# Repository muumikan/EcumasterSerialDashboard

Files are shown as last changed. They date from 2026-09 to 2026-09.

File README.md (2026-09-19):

# Ecumaster EMU Classic serial dashboard

A digital dashboard for a Toyota Carina with a 1G-GTE running an Ecumaster
EMU Classic. An ESP32-S3 reads the ECU's serial data stream and renders it on
a 3.5" touch panel.

**The link is read-only.** Nothing in the firmware writes to the ECU port,
and the ECU's extension port is a one-way stream in the first place.

## Hardware

| Part | Detail |
|---|---|
| Display / MCU | Elecrow CrowPanel Advance 3.5" HMI, ESP32-S3-WROOM-1-N16R8 |
| Panel | ILI9488, 480 × 320 IPS, GT911 capacitive touch |
| Memory | 16 MB flash, 8 MB octal PSRAM |
| Level shifter | MAX3232 (RS-232 ↔ 3.3 V TTL) |
| Clock | BM8563 RTC at 0x51, CR1220 cell diode-OR'd through a BAT54C |
| Storage | microSD on its own SPI bus, FAT16/FAT32 |
| ECU | Ecumaster EMU Classic, firmware 1.211 |
| Link | EDL-1 logger stream, 115200 baud, 8N1, one direction only |
| ECU port | EMU Classic extension port (replaces the BT Module) |

The dashboard replaces the Ecumaster BT Module on the EMU Classic's extension
port. That port speaks RS-232 voltage levels, which would destroy an ESP32
GPIO, so a MAX3232 sits between them — powered from the ECU at 3.3 V, never
5 V. See [wiring/signal-list.md](wiring/signal-list.md); the supply rule there
is the one that decides whether the board survives.

## What it shows

Eight pages, switched by swiping horizontally. Only channels that have a sensor
actually fitted to the car appear anywhere; VSS and EGT are streamed by the
ECU but not wired, so they are not displayed.

The pictures below are drawings of each page at the panel's own 480 × 320,
produced by [docs/mockup/render.py](docs/mockup/render.py) from the same
numbers the firmware uses. They are not screenshots — nothing here has been
photographed off the panel yet — so treat them as the layout, not as proof it
renders this way.

| | |
|---|---|
| **1 · Drive** — RPM, boost with peak hold, CLT, oil pressure, lambda, battery | **2 · Tune** — AFR against target, knock, ignition, injector PW and duty, MAP, TPS, RPM |
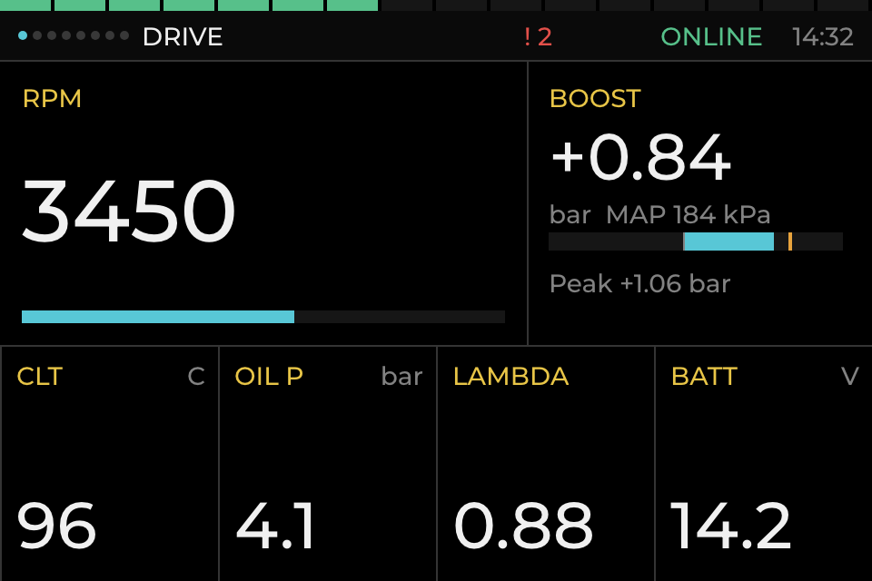
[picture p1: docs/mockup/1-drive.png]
Drive
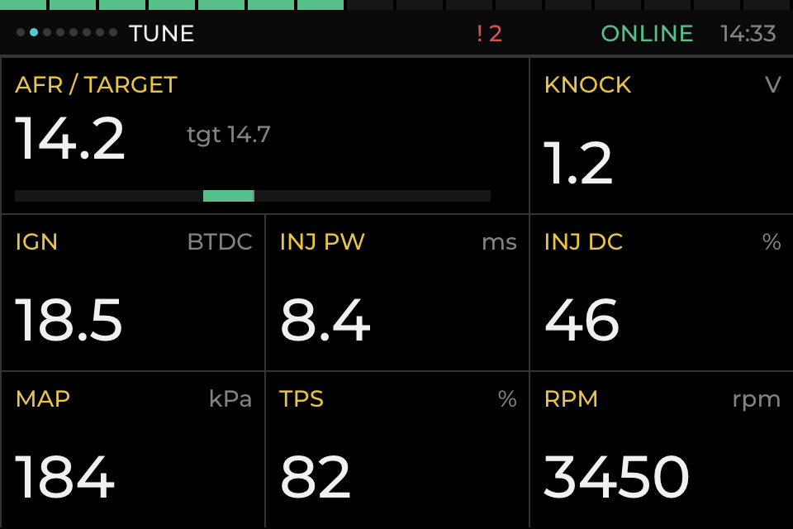
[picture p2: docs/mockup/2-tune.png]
Tune
|  |  |
| **3 · Temps** — CLT, IAT, ECU temp, oil pressure, fuel pressure, ΔFPR | **4 · Idle** — RPM against the idle target, valve duty, the PID's share, timing trim |
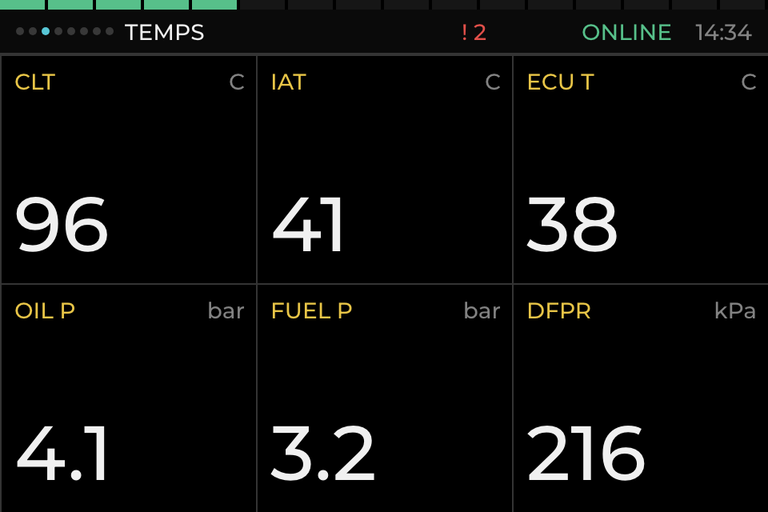
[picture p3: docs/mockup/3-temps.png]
Temps
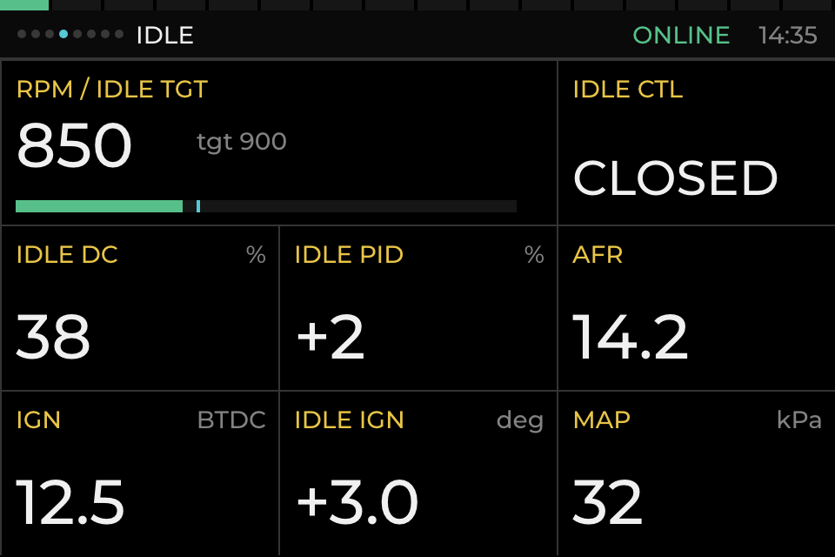
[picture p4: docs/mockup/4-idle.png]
Idle
|  |  |
| **5 · Boost** — MAP against the boost target, solenoid duty, PID and error correction | **6 · Alarms** — everything that tripped this run, newest first, with the time |
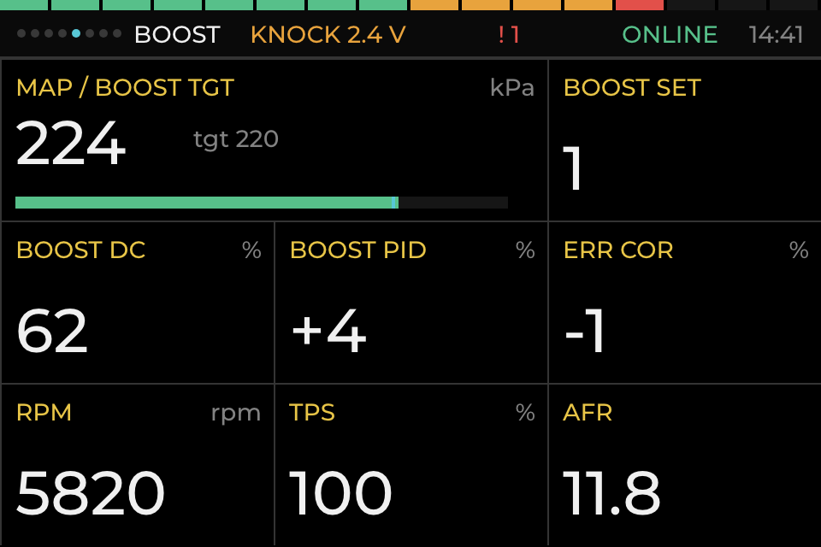
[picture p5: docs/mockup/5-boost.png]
Boost
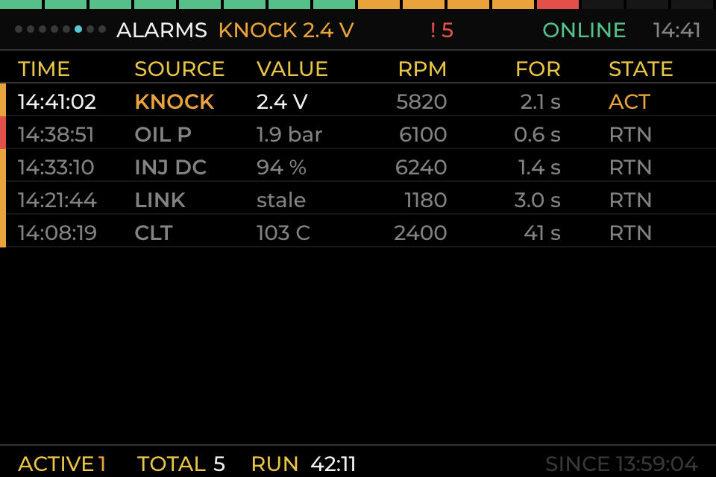
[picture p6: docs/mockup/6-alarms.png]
Alarms
|  |  |
| **7 · Diag** — link state, frame age, counters, what latched, CEL word, run peaks | **8 · Setup** — alarm limits and behaviour, shift points, brightness, logging |
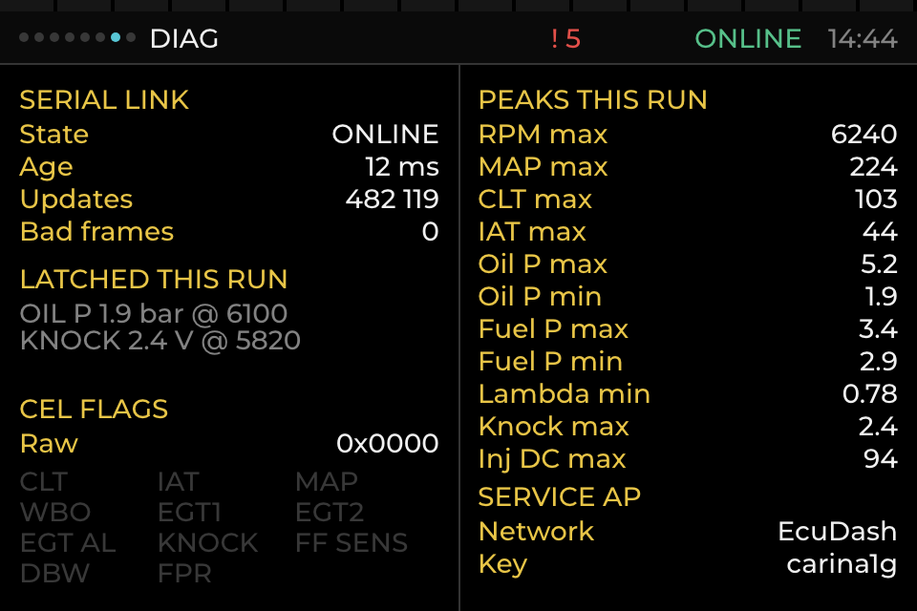
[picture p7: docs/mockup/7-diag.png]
Diag
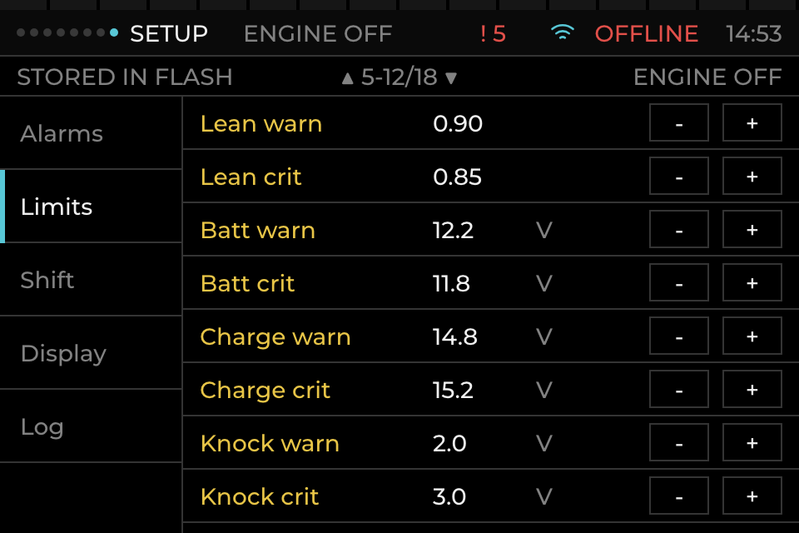
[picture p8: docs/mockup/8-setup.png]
Setup
|  |  |

Idle and Boost are pit work rather than driving pages, which is why they sit
after Temps rather than next to Tune. Both need the EDL-1 stream's control
channels; on a car whose ECU does not send them, they say so instead of
drawing zeros.

A measurement's name is yellow and its value white, everywhere on the
dashboard. Grey on black was the lowest contrast on the panel and it was on
the one element that says what you are looking at; yellow on black is also
what an Ecumaster dash looks like, so the panel matches the software beside
it.

Parked, with the engine stopped and the service access point up, the same
Drive page reads like this — the oil pressure cell showing what a critical
alarm does to a cell, and the status bar carrying the access point, a latched
count and the link all at once:

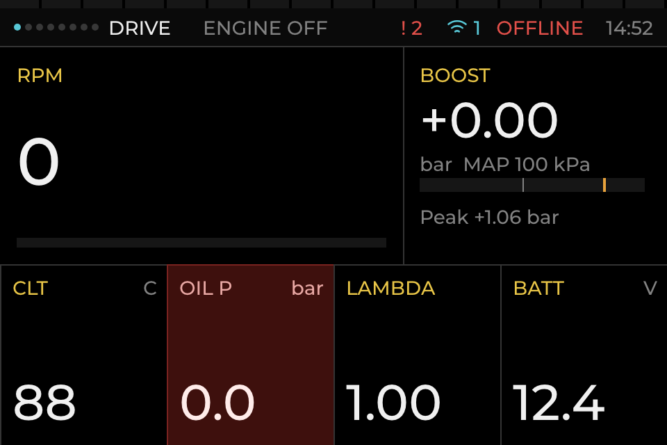
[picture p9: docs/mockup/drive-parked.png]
Drive, parked, with the access point up


Above every page sit two always-on layers: a 6 px shift-light strip, lit from
1 000 rpm and red from 6 000, and a status bar carrying the link state, the
worst active alarm and the time of day regardless of which page is up. The car
has no clock in its own instrument cluster, so this is the only one.

The page changes only when you swipe it. There is no idle timeout returning to
Drive: on the car it moved the screen out from under you while you were still
reading it.

An out-of-range value lights its own cell — amber for a warning, red for
critical — and names itself in the status bar. Nothing but a swipe ever changes
the page. Every trip is recorded with its time, the value, the RPM it happened
at and how long it lasted, so a half-second dip is still there when you stop.

The Alarms page lists those records newest first. Limit crossings, the ECU's
check-engine bits and the health of the serial link all land in the same list,
because a loose connector and a hot engine are both things you want to see in
the order they happened. Nothing is acknowledged and nothing is cleared by
hand: it is a log to read, not a queue to work through.

Alarms arm only after the engine has been running for a few seconds. Cranking
crosses 500 rpm while oil pressure is still building and the battery is still
down from the starter, and without the delay every start would fire two
critical alarms. Thresholds carry a deadband so a value sitting on its limit
does not flicker.

Limits, the arming delay, the deadband, the shift points and the backlight are
all editable on the Setup page and stored in flash — no laptop, no reflash. The
page stays usable with the engine running, because setting a limit without
watching the value it guards is guesswork.

At power-up the dash opens on Drive and sweeps the shift lights, so every
segment is confirmed working before the car moves.

## The serial link

The dashboard reads the EMU's **EDL-1** logger stream: 260-byte frames at
115200 baud carrying all 195 channels from one instant, rather than the older
protocol's 34 channels arriving one 5-byte frame at a time. The ECU has to be
configured to send it.

The classic protocol was supported too, chosen by a build flag, until it was
removed — it could not produce a `.emulog` at all, and was compiled on every
change without ever being run. See the
[decision log](docs/decision-log.md). The adapter seam it justified is still
there, so adding a protocol back costs nothing above that line.

The channels are listed in [docs/edl-channels.md](docs/edl-channels.md); most
are not on screen yet.

## Service page

With the engine stopped, the dashboard raises a WiFi access point and serves a
maintenance page on it: download or delete the logs, edit the same settings the
panel holds, set the clock from the browser, and read the diagnostics that
otherwise need a USB cable behind the dash.

Join `EcuDash` and open `http://192.168.4.1/`. It is off until switched on
under `Log` on the setup page. Full details, including why the engine has to be
stopped, are in [docs/service-page.md](docs/service-page.md).

## Building

The project uses [PlatformIO](https://platformio.org/).

```bash
pio run                     # build
pio run -t upload           # build and flash over USB-C
pio device monitor          # 115200 baud USB CDC console; press any key for the state
```

There is one environment, `crowpanel_advance_35`, so no `-e` is needed. If
`pio` is not on your `PATH`, it lives at `~/.platformio/penv/bin/pio`.

Dependencies (LovyanGFX and LVGL 8.3) are pulled automatically. The EDL-1 field
extraction is vendored in `lib/EDLSerial/` — it is
[ThiloZ/EDLSerial](https://github.com/ThiloZ/EDLSerial) (MIT), with the framing
done in this project instead; see
[docs/architecture.md](docs/architecture.md) for why.

## Layout

```
include/            headers, one per module
src/protocol/       EdlSerialAdapter — the only place that knows the wire format
src/data_model/     EngineDataModel — the single source of truth for the UI
src/ecu/            EcuDataProvider — owns UART1
src/alarms/         AlarmEngine — thresholds in one rule table, and the event log
src/screens/        LVGL pages, tiles, chrome and navigation
src/diagnostics/    diagnostics page and the serial text report
src/logging/        EmuLog — .emulog files to the SD card
src/hal/            display, touch and RTC bring-up
src/web/            service access point, HTTP server and the page it serves
docs/               architecture, protocol, decisions, vendor change logs
docs/mockup/        drawings of the eight pages, and the script that makes them
hardware/ wiring/   pin assignment and the ECU-to-dash signal chain
```

See [docs/architecture.md](docs/architecture.md) for how the layers fit
together and [docs/decision-log.md](docs/decision-log.md) for why they are
shaped that way.

## Status

**Runs on the car.** Tested connected to the ECU on 8 and 9 September 2026. On
EDL-1 the link runs clean with no dropped frames, values read correctly and the
alarm list behaves. See [docs/test-results.md](docs/test-results.md).

Working: the EDL-1 link, data model, alarm engine, eight pages, swipe
navigation, settings in flash, the real-time clock, SD logging, and the service
access point with its page — access point, page, log download and clock sync
confirmed on the car on 16 September 2026.

The 19 September session found three defects, all fixed: the SETUP page's
Limits category rebooted the board by exhausting LVGL's object pool, and every
write the service page accepts was refused because a dead ECU leaves its last
rpm frozen in the snapshot, which then reads as a running engine. Logs are
written into a folder per day from that session on.

Not yet exercised on the car: the multi-file `.tar` download, deleting logs,
starting the engine mid-download, and the idle timeout. They are listed with
what to look for in [docs/test-results.md](docs/test-results.md).

One thing to know about the parts that work. The SD card has mounted intermittently
on the bench for reasons nobody has established; `EmuLog` retries and says
which attempt worked, so the console tells you if it happens again.

Open items are listed in [docs/decision-log.md](docs/decision-log.md).

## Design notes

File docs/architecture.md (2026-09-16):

# Architecture

The rule the code is written against: **the UI never learns the wire format,
and the protocol layer never learns about timing or pixels.** Each layer below
only knows the one under it.

```
   ServicePage ◀── ServiceAp     WiFi access point, engine stopped only
        │                        logs, settings, clock, diagnostics
        │
        ▼
        LVGL screens              DashUi, MainScreen, TuneScreen, TempsScreen,
              │                   IdleScreen, BoostScreen, AlarmsScreen,
              │                   DiagnosticScreen, SetupScreen, Tile
              │
              │   DashSettings ◀──▶ SettingsStore (NVS)
              │        │            numbers and flags only
              │        │            SetupItem table shared by both editors
              ▼        ▼
        AlarmEngine ──────────┐   one rule table, limits from settings
              │               │   arming delay, hysteresis, latching
              ▼               ▼
        EngineDataModel ──────┘   snapshot in engineering units,
              │                   link health, revision counter
              ▼
        EcuDataProvider           owns UART1, stamps arrival times
              ▼
        EcuLinkAdapter            EdlSerialAdapter - EDL-1, 195 channels
              ▼                   named by ecu_link.hpp
        UART1  ◀── MAX3232 ◀── EMU Classic
```

## The layers

### Adapter — `src/protocol/`

One, behind an interface that could hold more. `ecu_link.hpp` names it and
supplies the baud rate; nothing above this layer knows what a frame is.

There were two. The EMU's older 35-channel serial protocol lived here beside
EDL-1, chosen by a build flag, until it was removed: the car runs EDL-1, and
the classic build could not log at all, because the `.emulog` record *is* an
EDL-1 frame. It was compiled on every change and never once run. The seam it
justified is worth keeping anyway — swapping protocols cost no change to the
model, the alarms, the screens or the settings, and would not again.

#### EdlSerialAdapter

The EDL-1 logger stream: 260-byte frames at 115200 carrying all 195 channels
from one instant. Field extraction comes from the vendored
[ThiloZ/EDLSerial](https://github.com/ThiloZ/EDLSerial) (MIT); framing is done
here, because the protocol carries no checksum and the library's own
resynchronisation is wrong.

Three things earn the confidence a checksum would otherwise give: a one-byte
sliding window to find the marker, a refusal to accept a frame until the next
marker appears exactly 260 bytes later, and a plausibility check that rejects
values which cannot be real. The adapter keeps the last *good* frame rather
than the last frame, so a bad sample never reaches the run peaks.

Every frame it accepts is also handed to the logger, which strips the four-byte
marker and compresses the rest. That is a tee, not a second decode.

### EngineDataModel — `src/data_model/`

The single source of truth. Holds the latest `EngineSnapshot`, when it
arrived, and a `revision()` counter that advances **only when a value actually
changed**, so the UI can skip redraws with one integer comparison.

Link health is derived from arrival timing alone: `Online`, then `Stale` after
500 ms, then `Offline` after 3 s.

### EcuDataProvider — `src/ecu/`

Owns `HardwareSerial(1)`, opens it with no TX pin, drains it, and stamps the
model. The seam between hardware and application state.

### AlarmEngine — `src/alarms/`

Evaluates the snapshot against a fixed rule table: each rule gives a severity,
a status-bar string, and the page that displays the value. Sitting beside the
model rather than inside the screens means a threshold is changed in one place
and every page agrees.

Three behaviours are deliberate. Alarms arm only after the engine has been
running for the arming delay, so cranking cannot trip them. Thresholds carry a
deadband so a value on its limit does not flicker. And every trip is latched
with its worst value and the RPM it happened at, because a half-second dip is
exactly what a live-only display loses.

No alarm ever changes the page.

### Screens — `src/screens/`, `src/diagnostics/`

`DashUi` owns everything that is always on screen — the shift-light strip, the
status bar, the page dots — plus navigation: swipe gestures, the critical-alarm
page request, and the 30-second return to the driving page.

Each page implements `DashPage`. Pages receive the model, the alarm state and
the run peaks; they hold no thresholds and no protocol knowledge. `Tile` is
the shared measurement cell and owns its own severity colouring.

Eight pages, ordered by when they are wanted: DRIVE, TUNE and TEMPS are worth
a glance while moving, IDLE and BOOST are pit work, and ALARMS, DIAG and SETUP
are read standing still.

IDLE and BOOST show closed-loop control state, which only the EDL-1 stream
carries. They read `EngineSnapshot::controlChannels` rather than a build flag,
and show `n/a` when it is false. That keeps the protocol choice where it
belongs - in the adapter - and it is not cosmetic: 0 % is also what a closed
idle valve reads, so absence has to be stated rather than implied.

Only the visible page is updated, and only when the model's revision moves.

### Settings — `src/settings/`

`DashSettings` holds everything the driver can change: alarm limits and
enables, the arming delay and deadband, shift points, backlight and logging. `SettingsStore` keeps it in NVS as one versioned blob, so a
firmware change that alters the struct falls back to defaults rather than
reading old bytes as new fields.

Only numbers and flags live there. Which value an alarm watches and which way
it trips stays in the rule table in code.

### Display — `src/hal/`

LovyanGFX panel and GT911 touch configuration, and LVGL bring-up. Keeps the
panel wiring out of the screen code. Draws through two partial buffers in
internal DMA-capable RAM rather than full-screen buffers in PSRAM, which
flushes faster.

## Data flow, one iteration

```
AppController::loop()
  provider.loop(now)      drain UART → decode → model.applySnapshot()
  ui.update(model, now)   if revision moved: evaluate alarms, record peaks,
                          repaint shift lights, status bar, visible page
  display::loop()         lv_timer_handler()
  report.update(...)      text diagnostics on the USB console
```

`main.cpp` is two lines. Everything else hangs off `AppController`.

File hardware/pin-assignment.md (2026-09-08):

# Pin assignment — CrowPanel Advance 3.5" HMI

Board: Elecrow CrowPanel Advance 3.5" HMI, ESP32-S3-WROOM-1-N16R8
(16 MB QIO flash, 8 MB octal PSRAM).

These numbers are transcribed from Elecrow's own material, not guessed:

- [Elecrow Wiki — CrowPanel Advance 3.5-HMI](https://www.elecrow.com/wiki/CrowPanel_Advance_3.5-HMI_ESP32_AI_Display.html)
- [Elecrow-RD demo repository](https://github.com/Elecrow-RD/CrowPanel-Advance-3.5-HMI-ESP32-S3-AI-Powered-IPS-Touch-Screen-480x320),
  `example/V1.0/Arduino/lesson-03` (`LovyanGFX_Driver.h`, `touch.h`) and
  `lesson-05` (expansion port)

The firmware's copy of this table is [`include/board_config.hpp`](../include/board_config.hpp).
Change it there; this file documents it.

## Used by this project

| GPIO | Function | Notes |
|---|---|---|
| 18 | **ECU serial RX** | UART1-OUT connector RX, fed from the MAX3232 |
| — | ECU serial TX | Deliberately unassigned. The connector's TX is GPIO17. |
| 42 | LCD SCLK | ILI9488 on SPI2_HOST, 40 MHz write |
| 39 | LCD MOSI | |
| 41 | LCD DC | |
| 40 | LCD CS | |
| 2 | LCD RST | |
| 38 | LCD backlight | LEDC PWM, channel 0, 5 kHz / 8 bit — brightness and night mode |
| 15 | Touch I2C SDA | GT911, shared with the on-board RTC |
| 16 | Touch I2C SCL | **See the conflict note below** |
| 47 | Touch INT | |
| 48 | Touch RST | |

GT911 address is `0x14`; the wiki also lists `0x5D`. If touch does not
respond, try the other one — `board::kTouchI2cAddr`.

The panel is physically 320 × 480 portrait. `offset_rotation = 3` presents it
as 480 × 320 landscape, which is what the UI is laid out for.

## Conflict note: GPIO16

**GPIO16 is the GT911 touch I2C clock on this board.** The first bring-up ran
on a generic esp32dev board with the ECU RX on GPIO16, which is fine there but
collides with touch here. When the project moved to the CrowPanel the ECU
input was re-pinned to GPIO18.

If you are following older notes or the original `main.cpp`, this is the wire
that has to move.

## Present on the board, unused by this project

| GPIO | Function |
|---|---|
| 6 / 4 / 5 | SD card MOSI / MISO / CLK |
| 11 / 13 / 12 | Speaker I2S LRCLK / BCLK / SDIN |
| 10 / 3 / 9 | Microphone SD / WS / CLK |
| 8 | Buzzer |
| 45 | Mode select: microphone vs. wireless module |
| 44 / 43 | UART0-IN connector RX / TX |
| 17 | UART1-OUT connector TX |

GPIO 33–37 are consumed by the octal PSRAM and are not available.

## Console

The debug console is USB CDC at 115200 baud over the USB-C connector
(`ARDUINO_USB_CDC_ON_BOOT=1`). This is separate from the ECU link, which runs
at 19200 on UART1.

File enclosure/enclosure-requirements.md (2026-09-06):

# Enclosure requirements

A 3D-printed housing for the CrowPanel Advance 3.5" and the MAX3232, mounted
in the cabin of a Toyota Carina.

## What it has to do

**Survive a car.** Vibration is constant and the dashboard sees a wider
temperature range than a desk. Nothing may rely on friction alone: the panel
is retained mechanically, and the case is retained mechanically to the car.

**Be readable at a glance while driving.** The screen is the whole point of
the object. That drives three things: the bezel is as thin as printing allows
so the 480 × 320 area is not cropped, the face is angled toward the driver
rather than sitting flat, and the surface around the screen is matt black so
windscreen reflections do not wash it out. A glossy print here is a real
usability defect, not a cosmetic one.

**Keep the level shifter inside.** The MAX3232 is a small module on the ECU
side of the wiring. Housing it in the same case means one cable leaves the
enclosure toward the ECU and one USB-C cable leaves for power, instead of a
loose board taped behind the dashboard.

**Not trap heat.** The ESP32-S3 driving an LVGL UI at 40 MHz SPI is not hot,
but a sealed black box on a sunny dashboard is a different matter. Vents on
the back and bottom, none on top where they would collect dust and drink.

**Come apart.** Firmware is flashed over USB-C, so that port stays reachable
without opening anything. Everything else — reseating the ECU cable, swapping
the MAX3232 — should need one screwdriver and no cutting.

## Fixed constraints

| | |
|---|---|
| Display active area | 480 × 320 px, 3.5" diagonal |
| Panel orientation | Landscape |
| Touch | Capacitive — the bezel must not overhang the glass edge |
| Ports used | USB-C (power and flashing), UART1-OUT connector (ECU) |
| Ports unused | UART0-IN, SD card, speaker, microphone |

The capacitive touch point matters: a GT911 digitiser registers touches near
the glass edge, and a bezel lip that sits over the active area both hides
pixels and creates dead zones. The opening is sized to the glass, not to the
picture.

## Deliberately out of scope

Waterproofing, an internal battery, and a mount design. The mount is
car-specific and belongs in [mounting-notes.md](mounting-notes.md).

## Print settings that matter

- **Matt black filament** for the front. PETG or ASA rather than PLA: a PLA
  case will sag on a sunny dashboard, and this is not a hypothetical.
- **Screw bosses need walls**, not infill. Four perimeters minimum around
  every boss and around the screen opening.
- **Print the front face down** so the visible surface is the smooth build
  plate side and the bezel opening needs no support.

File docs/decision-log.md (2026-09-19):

# Decision log

Why the project is shaped the way it is. Newest first.

---

## A measurement's name is yellow, and its unit is on the caption's line

Two changes that came out of reading the panel in the car rather than on a
desk, and they are the same change.

The name of a measurement was grey on black, which is the lowest contrast
anywhere on this dashboard, on the one element that tells you what you are
looking at. It is yellow now. That is also what an Ecumaster dash looks like,
so the panel matches the software it sits beside; a driver who knows one reads
the other without relearning it.

The yellow is `#E8C547` and is deliberately clear of the warning amber
`#E8A33D`, which has red in it. The two are never far apart on screen and must
not be confused: one is a name, the other is a verdict.

The unit moved from the bottom right of the cell to the top right, beside the
name. Bottom right put it on the value's own baseline, which meant every
increase in the value's size walked the two closer together - and the values
did need to grow. It also reads better: what this is and what it is measured
in are the same kind of fact, and the line below is then the value's alone.

Values on the three-across pages went from 28 px to 36 px, which is the
largest LVGL's built-in Montserrat offers that still fits a 160 x 95 cell
under its caption. 48 does not: its line box is 52 px against 79 px of cell
inside the padding, which leaves nothing for the caption. The one cell that
stayed smaller is IDLE CTL, because it holds a word rather than a number, and
"CLOSED" is 154 px at 36 - wider than the cell.

---

## The status bar is slots, not offsets

Everything on the status bar now sits in a slot given as a fixed left edge and
a fixed width, and clips to it. It used to be placed by eye: each item at an
offset from the right edge, and the alarm line simply centred.

Those two arrangements did not know about each other. Park the car with the
access point up and "ENGINE OFF" grew leftwards from the centre underneath
"WIFI", which is the one situation where both are shown - so the bug was
invisible on the bench and unavoidable in the driveway.

The widths are measured rather than guessed, by reading the advance widths out
of `lv_font_montserrat_14.c` for the longest string each slot can hold. That
turned up a second latent bug: "OFFLINE" is 63 px, and the slot that looked
about right was 62.

The access point indicator became LVGL's wifi glyph instead of the word. It
says the same thing in a third of the width, on a bar that had already run out
of room once.

---

## Target and actual share one absolute scale

TUNE draws mixture as a deviation bar: AFR minus target, centred, ±1.8 across
the width. IDLE and BOOST were specified to work "like the AFR bar", and they
do not. Both draw the actual value as a fill on an absolute scale with the
target as a mark on that same scale.

A deviation bar answers "how far off are we", which is only a question while
the loop is closed and aiming at something. Mixture always has a target. Idle
does not: drive away and idle control opens, the target stops meaning
anything, and a deviation bar sits pegged for the rest of the session looking
exactly like a fault. Boost is worse - most of any drive is spent nowhere near
target, by intent.

An absolute bar degrades into something still true: a rev counter, and a
pressure gauge. The target mark simply disappears when the ECU is not asking
for one, which it signals by sending zero.

The scales are 0–2000 rpm and 0–220 kPa. Both are chosen so the interesting
region sits in the middle of the bar rather than at one end: idle targets run
850–1500, and 220 kPa puts atmospheric just under halfway, so off boost is a
position the eye recognises instead of a number it has to read. Driving pegs
the idle bar, which is the honest behaviour for a scale that stops at 2000.

BOOST shows absolute kPa, while DRIVE shows gauge bar. That is deliberate:
`boostTarget` is stated in absolute kPa by the ECU, and converting one half of
a comparison puts arithmetic between the driver and the thing being compared.
DRIVE is for driving and bar is what a driver thinks in; BOOST is for setting
up the loop and kPa is what the loop is configured in.

## Absence is a value, and a zero cannot say it

The classic 35-channel protocol carries no idle or boost channel at all, so on
that build both new pages have nothing to show. Nothing distinguishes that from
a working loop: a closed idle valve, a settled PID and a missing channel all
decode to 0.

So `EngineSnapshot` carries a `controlChannels` flag, set by the adapter that
filled the snapshot, and the pages print `n/a` when it is false. Two
alternatives were rejected. An `#ifdef` in the page would put protocol
knowledge back into the UI, which is the one thing this project's layering
exists to prevent. Leaving the zeroes on screen would have the dashboard state
something false with no way for the reader to tell.

## The decoder is checked by a script, not by an eye

A manual pass over the vendored EDL decoder cross-checked all 195 channels
against Ecumaster's format definition and fixed 22 of them. It also missed
three, and the way it missed them is instructive: `cam1AngleTarget` and
`cam2AngleTarget` were both caught, and `cam1Angle` and `cam2Angle` sitting
directly above them were not. The eye read the group as done.

`tools/edl_check_storage.py` now re-derives every channel's storage and
divider from the XML and compares them against what `parseFrame()` does. It
reuses the same parser `emulog_inspect.py` already had, so there is one
definition of what a byte means, and it exits non-zero so it can gate a build.

The third miss, `idleAngleCorr`, is the reason this matters rather than a tidy
story: idle ignition correction is negative whenever the ECU pulls timing to
hold the target, so the channel was wrong at precisely the moment the new IDLE
page exists to show it.

## The logs go to the laptop, not to a cloud

The first plan for getting logs off the card without carrying it indoors was an
upload to Google Drive over the home WiFi. It was worked out in some detail -
OAuth with a refresh token in flash, TLS with pinned Google roots, resumable
uploads in 256 kB chunks, NTP so the certificate dates would validate - before
one fact about the workflow undid all of it.

The logs are read in EMU Classic Client, which runs on the Windows tuning
laptop. That laptop comes to the car anyway. So the cloud route was car → Drive
→ download back onto that same laptop: strictly longer than car → laptop, and
paid for with OAuth, certificate maintenance and a long-lived secret in a
firmware image anyone can dump.

The laptop's wireless is dedicated to this, so the network is ours to choose.
The dashboard raises its own access point and serves a page. What went away:
OAuth, TLS, root certificates, token expiry, the cloud quota, compile-time WiFi
credentials, and NTP - the browser's own clock sets the RTC, which needs no
internet at all. What was gained: it works in a garage, at a track, anywhere.

## The access point only runs with the engine stopped

Not a safety rule, though it reads like one. It is what keeps the feature small.

With the engine off the ECU sends nothing, so nothing is written to the card
while the server reads from it. No second task, no mutex, no SD card shared
between two cores - the server runs in the same cooperative loop as everything
else. The one failure this feature could plausibly have caused, a corrupted log,
is designed out rather than guarded against.

The cost is real and worth naming: a live view of all 195 channels would be the
most useful thing on that page when chasing a decoder bug, and it is impossible
here, because with the engine stopped there is nothing to show.

Guards exist because the alternator is not charging while this runs: a settle
delay, a voltage floor, and a fifteen-minute idle timeout that latches until the
engine runs again. See [service-page.md](service-page.md).

## Deleting logs from the page, after deciding not to

An earlier draft left deletion out, reasoning that a 32 GB card holds years of
logs at 4.7 MB per hour of driving, so nothing would ever need removing.

That argued about space when the question was about handling. Clearing the card
without deletion means taking it out and carrying it to a reader, which is the
exact chore the page exists to remove. It is in, with a confirmation that names
the files, no "delete all" form on the server, and a refusal to touch the file
currently being written.

---

## The battery and fuel-pressure alarms start switched off

Every alarm shipped enabled. Two of them should not.

The battery alarm trips on a charging system that dips under load, which is
most of them, and tells the driver something they already know. The fuel
pressure alarm has a worse problem: which Analog In carries fuel pressure is
still unconfirmed on this car, so the threshold may be watching a channel that
measures something else entirely.

An alarm that cries wolf does not cost nothing. It costs attention that the
real ones need, and it teaches the driver to look away from the status bar.
Both stay in the code, keep their thresholds, and are one tap away on the
setup page — they just do not arrive armed.

The settings version went to 3 to make this reach a device that already has a
stored record. Nothing about the record's shape changed; the bump only forces
the old one to be dropped. It takes brightness and the shift points with it,
which have to be set once more after the update.

---

## The alarm list scrolls, and the page gets first refusal on a swipe

The list holds 32 events and eleven fit on the screen, so a busy run put the
oldest 21 somewhere the driver could not reach.

Up and down now scroll it, a screen at a time with one row of overlap. The
mechanism is a virtual on `DashPage`: a swipe is offered to the page on screen
before it turns the page, and the page says whether it used it. Only the alarm
list takes anything, and only up and down — left and right stay reserved for
navigation everywhere, because a page that can trap the driver on itself is a
page that gets sworn at in traffic. A scroll that has hit the end reports the
swipe as unused rather than swallowing it.

A new event resets the scroll to the top. The newest is the one worth reading,
and it is the one that just happened.

---

## The palette is true greys now, because the panel is not neutral

The pass that darkened the value tiles left them at colours like `0x0D1113` —
green and blue a few counts above red. On paper that is a neutral so close to
black that the tint should not exist. On the panel in the car it read as a
green cast across every number on the screen.

So every grey in the theme is now R = G = B, and the tile background is plain
black. Where a tinted grey was replaced the luminance is unchanged, so the
only difference is hue. The warning and critical fills stay coloured; they are
supposed to be.

The lesson is about the display rather than the design: a 3.5" IPS driven by
an ILI9488 is not neutral enough to be trusted with a tint nobody asked for.
If a colour is meant to read as black, make it black.

---

## The log format is the EDL-1 frame, minus four bytes

The `.emulog` file EMU Classic Client writes turned out to be a gzip stream
over a 12-byte header and 256-byte records, where each record is the 260-byte
EDL-1 frame with its `32 40 50 60` marker stripped. Nothing is assembled,
scaled or reordered on the way in.

This collapsed the logging task. The plan had been to synthesise a record
format and reverse-engineer a field map; instead the map was already in the
vendored decoder, and the file wants the bytes the UART is already delivering.
The right design is therefore to tap the frame *before* decoding, not to build
records out of decoded values — a decode bug can never corrupt a log that never
went through the decoder.

It also settles the EDL-1 choice made earlier for a different reason. Adopting
EDL-1 was argued on channel count and simultaneous sampling; that it puts the
exact bytes the log format wants on the wire was a guess at the time. It is now
a fact.

Established from Antti's own logs and CSV exports, then proven by writing a
file that opens in the Client. Full account in
[emu-log-format.md](emu-log-format.md).

---

## Ecumaster's XML outranks the vendored decoder

`lib/EMUSerial-master/` is vendored unmodified, on the principle that the
reference implementation is the specification available. `lib/EDLSerial/` is
not, and the difference is that for EDL-1 a better specification exists:
`docs/ecu-formats/version1_211.xml` is Ecumaster's own format definition, and
its `storage` attribute states every channel's width and signedness.

Checking all 195 fields against it found 22 the library decodes wrongly —
mostly signed values read unsigned, so a small negative reading appears as a
large positive one. Three were provably wrong in real logs: `wboIPMeas` and
`wboIPNorm` in 83 % of samples, `dwellError` in 23 %. `IgnAngle`, which the
dashboard displays, is among the latent ones: correct all through both sample
logs and wrong the moment the ECU pulls timing.

The fixes went into the library rather than a wrapper, because unlike the
framing defects there is nothing to wrap — the information is destroyed at the
point of the cast. Upstream's README invites editing the parser, and the
changes are listed in [`lib/EDLSerial/README.md`](../lib/EDLSerial/README.md)
so an upstream pull cannot quietly revert them.

One field was deliberately left alone. `fcProbability` divides by 2 in the
library and by 1 in the XML; upstream targeted firmware 1.226 against this
project's 1.211, the channel is zero in every log available, and neither
reading could be confirmed. An unverified change is not an improvement.

---

## The alarm list is a log, not an operator's queue

The list was first drawn with an acknowledge column and an ACK ALL button, the
way an industrial alarm list works. That was dropped before any of it was
written.

In a control room acknowledgement is part of a chain of responsibility: someone
is on shift, sees the alarm, and takes it. In a car the person in front of the
screen is driving. Nobody is standing by to act on a row, and an unacknowledged
alarm does not mean anyone has failed to respond to it - it means the driver was
busy driving, which is what they are supposed to be doing. A button whose only
effect is to dim some text is a button that takes attention off the road.

What remains carries the same information in two channels that cost nothing to
read. Brightness answers "is this true right now": active rows are bright,
returned rows are dim. Colour answers "how bad was it", and the severity stripe
keeps its full colour on returned rows too, so the history stays scannable
instead of going flat grey.

Nothing blinks either. Blinking is standard practice for an unacknowledged
alarm and wrong here for the same reason: it is movement in the driver's
peripheral vision.

## Alarms are recorded as events, not one slot per alarm type

`AlarmEngine` latches trips into `latched_[kAlarmCount]` - one slot per alarm
id, holding the worst moment. That answers "did this ever trip", which is what
the Diag page asks, and it cannot answer "what happened, and in what order".
A coolant warning at 14:33 and another at 14:41 are the same slot, and the
second one is invisible.

`EventLog` is a ring of the most recent events, newest first, each stamped with
the wall clock, the rpm at onset and how long the condition held. An event that
is already open escalates rather than duplicating, so a warning that becomes
critical stays one event.

Three sources feed it, and the two new ones are the point of the exercise. The
ECU's check-engine word was previously only ever shown as the bits set right
now, so a fault that came and went while driving left no trace at all. Link
health was a counter, and a loose connector produces clusters - which are
visible in a time-ordered list and invisible in a count.

The old latched list stays on the Diag page for now. It is redundant against
this and removing it is a UI change of its own.

## The clock is set from the build, and only when it cannot be right

There is no network and no GPS in the car, so the only time the firmware can
know is the moment it was compiled. `__DATE__` and `__TIME__` are written to
the RTC, and a Clock category on the Setup page was considered and dropped: the
clock is the RTC's state, not a setting, and it does not belong in the settings
blob.

The interesting part is when to write it. The first attempt used the RTC's VL
flag alone, which was wrong. VL says the oscillator stopped. It does not say
the time is right - a part kept alive by its backup cell since the factory has
a clock that has been running the whole time and has never been set, VL clear
throughout. That is exactly what this board had: the panel came up reading
00:24 while the firmware reading it had been compiled at 19:44.

The second trigger is plausibility. A clock cannot legitimately read earlier
than the moment the firmware reading it was compiled, so anything that does has
never been set. Once seeded the RTC runs ahead of the build time and the test
stops firing; flashing a newer build over a correct clock leaves it alone; and
a clock that has drifted slow gets nudged forward by every reflash, which is a
useful accident rather than a designed feature.

The cost is daylight saving. The seed carries whatever offset was in force when
the file was compiled, so twice a year the clock is an hour out and the fix is
a reflash. That was accepted deliberately rather than build a settings UI for
it.

## Alarms colour the cell and name themselves; they never move the page

An out-of-range value lights its own tile — amber for a warning, red for
critical — and the status bar names the worst one. The status bar is on screen
whichever page is up, so the driver already sees it.

Two more aggressive designs were built and then removed. A full-screen takeover
hid everything else at exactly the moment the driver most wants context. Pulling
the page that owns the value was gentler but still bought nothing the status bar
was not already showing, while taking the screen away from whatever the driver
had deliberately chosen to look at.

What remains is the quiet version: colour where the value lives, one line of
text that follows you across pages, and the page changes only when a thumb
changes it.

## The EDL-1 protocol replaced the classic one

The EMU streams either its classic serial protocol or the EDL-1 logger
protocol. The classic one sends 34 channels, one per 5-byte frame at 19200,
which means values arrive at different moments and have to be assembled into
something that never existed as a single sample. EDL-1 sends 260 bytes at
115200 carrying all 195 channels from one instant.

Three reasons, any one of which would have been enough: nearly six times the
channels, a genuine simultaneous sample rather than a rolling reconstruction,
and - the one that matters for logging - the same stream an EDL-1 datalogger
receives before writing the `.bgc` files EMU Classic Client opens.

Both live in the tree behind one interface, chosen at build time by
`ecu_link.hpp`, because they differ in baud and framing and the ECU is
configured for one or the other. The default build is EDL-1, since that is
what the car is set up for; building classic against an EDL-1 ECU produces a
dashboard that shows nothing.

Adopting it cost no change above the adapter layer. That was the point of
having one.

## Framing has to do the work a checksum would

The EDL-1 protocol carries no checksum. On the first drive that showed as
bursts of impossible values across several fields at once - a coolant maximum
of 27472 C, oil pressure at 15.9 bar, invented check-engine flags.

Several fields wrong at the same moment is the signature of a misaligned
frame, not a faulty sensor, and the cause was mundane: Arduino's default UART
receive buffer is 256 bytes, smaller than a single 260-byte frame and about
22 ms of slack at 115200. Any redraw or flash write that held the loop longer
dropped bytes, and a dropped byte splices two frames into one that still opens
with a valid marker.

The buffer is now 2048 bytes, and three checks stand behind it because the
loop will stall again eventually: a one-byte sliding window rather than the
vendored library's discard-everything approach, which preserves a phase error
forever; a refusal to accept a frame until the next marker lands exactly 260
bytes later, which is the thing a splice cannot fake; and a plausibility gate
using Ecumaster's own `maxLimit` values.

The last piece matters most in practice. The adapter keeps the last *good*
frame rather than the last frame. One bad sample used to be permanent, because
it went straight into the run peaks and stayed there for the rest of the drive.

## The page changes only when a thumb changes it

Two mechanisms used to move it on their own, and both are gone.

A critical alarm used to pull up the page showing the value. It bought nothing
the status bar was not already saying, and it took the screen away from
whatever the driver had chosen.

An idle timeout used to return to Drive after thirty seconds. On the car that
turned out to be worse: it moved the screen out from under you while you were
still reading a page you had deliberately opened. Manual is the whole rule now.

## A run ends when the data stops, not when the revs do

The engine-off summary keyed on RPM falling below the running threshold, and
on the car it never appeared.

Killing the ignition cuts the ECU's power as well, so the last frame it ever
sends freezes at whatever the engine was doing - often several hundred rpm -
and the model faithfully keeps reporting it. Waiting for that number to fall
waits for ever.

The summary now closes the run when the engine stops *or* the link goes
offline, and it is checked on every pass rather than only when a frame arrives.
That second half matters as much as the first: the situation it exists for is
precisely the one where frames have stopped.

## Settings live in flash, and only numbers live there

The setup page edits an `AlarmSettings`/`DashSettings` struct saved to NVS as
one versioned blob. The version is bumped whenever the struct changes shape, so
an update that removes a field comes up on defaults rather than reading the old
bytes as new ones. Which value an alarm watches and which way it trips stays
in the rule table in code.

That line matters. A settings page that can rewire logic is a settings page
that can brick the dash on a dark road; one that can only move numbers cannot
produce a state the code has not already been written to handle. The stored
record carries a magic word and a version, and a mismatch falls back to
defaults rather than reinterpreting old bytes as new fields.

The page stays editable with the engine running. Locking it while stopped was
the first design and it was wrong: setting an oil pressure limit without
watching the live value it guards is exactly the guesswork the page exists to
end.

## Alarms arm on a delay, not on RPM alone

Gating on RPM > 500 alone fired on every start. Cranking crosses 500 rpm while
oil pressure is still building and the battery is still down from the starter,
so two critical alarms went off every time the engine caught - the fastest
possible way to teach a driver that red means nothing.

The engine now has to have been running for the arming delay before anything
can trip, and the status bar counts it down rather than going silently quiet.
The default started at three seconds and was raised to six after watching a
real start: oil pressure had not finished building by three.

## Thresholds carry a deadband, and trips latch

A value resting on its limit flickered its cell at the frame rate. An alarm now
trips at the limit and clears only once the value has moved back past it by the
hysteresis share.

Latching matters more. A half-second oil pressure dip in a corner is the event
most worth knowing about and the one a live-only display loses completely. Each
alarm keeps its worst moment - value and RPM - until the run ends.

## Alarms are gated on RPM > 500

With the key on and the engine stopped, oil pressure reads 0 bar and battery
voltage sits near 12.4 V. Both would be critical by any sensible threshold,
and neither is a fault.

Gating on the engine actually turning is simpler and more honest than
special-casing each rule, and it makes the intent obvious in one constant:
`kEngineRunningRpm`.

## CEL bits are named, once a source for the names existed

The 16-bit `cel` word is decoded by the reference implementation, but the
meaning of each bit is not documented there. An early mockup carried plausible
labels — CLT, IAT, TPS and so on — and those were invented, so the page shipped
with bare numbered bits instead.

The names turned up later in Ecumaster's own format definition, in the 1.211
XML that came off a USB stick, as `<paramlist name="checkEngine">`. Five of the
invented labels happened to be right and three were not, which is roughly what
guessing is worth.

The page now names the eleven defined bits. One inference remains — that the
list's entry N is bit N-1 — and it is written down in
[ecu-protocol.md](ecu-protocol.md#check-engine-bits) with the field-width
argument for it and a way to check it on the car.

## Unwired channels appear nowhere

The ECU streams all 35 channels whether or not a sensor exists. Reading the
car's schematic showed that VSS, both EGT inputs, oil temperature, fuel level,
flex-fuel content and gear position have nothing behind them.

Displaying a confident `0` for a channel with no sensor is worse than
displaying nothing, so those channels are absent from every page. This is a
per-car decision, which is why it is recorded here rather than inferred from
the code.

## The dashboard replaces the Ecumaster BT Module

The car's schematic showed a Bluetooth module on the EMU Classic's extension
port. The dashboard takes that place rather than sharing the port, which
settles what it plugs into and where its level shifter is powered from.

The BT Module manual then decides the electrical detail: that port supplies
**3.3 V**, it also exposes a +5 V pin that "must not be used", and 5 V "may
result in permanent damage". The MAX3232 is therefore powered from the ECU at
3.3 V, and the panel's own 3.3 V rail is not bridged to it — only grounds are
common. See [../wiring/signal-list.md](../wiring/signal-list.md).

The manual also confirms the stream's shape: *"Data transmission: One-way
(ECU → external device)"*.

## The ECU TX line is wired, and read-only is enforced in software

This reverses an earlier decision. `board::kEcuTxPin` was `-1` so that
`HardwareSerial::begin()` never attached a transmit pin, making a stray
`write()` physically harmless.

It is now GPIO17, because that is the wiring and the configuration the link
was actually verified working with. Changing the pinout at the same time as
everything else would have meant debugging two things at once if the first
flash had stayed silent.

The read-only guarantee is therefore a software one: the provider and the
adapter are the only files that touch the ECU port, and neither ever calls
`write()` or any other transmitting method. The port being one-way by design
means nothing is listening anyway.

If the hardware guarantee is wanted back, setting `kEcuTxPin` to `-1` restores
it in one line — the pin is assigned but never driven either way.

## ECU RX moved from GPIO16 to GPIO18

Bring-up ran on a generic esp32dev board with the ECU on GPIO16. On the
CrowPanel Advance 3.5, **GPIO16 is the GT911 touch I2C clock**.

The ECU input moved to GPIO18, the RX pin of the board's UART1-OUT connector.
This requires a physical change to the loom, not just a rebuild.

## Target moved fully to the CrowPanel; esp32dev dropped

The esp32dev environment was a protocol bring-up rig. Once the CrowPanel was
on the bench there was no reason to carry a second PlatformIO environment, so
it was removed rather than kept "just in case".

## Pin numbers are transcribed, never guessed

Every GPIO in `board_config.hpp` carries a source comment pointing at
Elecrow's wiki or their demo repository. The same standard the project applies
to the ECU protocol — *do not invent protocol details* — applies to hardware:
a wrong pin number costs a board, and a plausible guess is indistinguishable
from a fact once it is written down.

## The protocol decoder is vendored, not reimplemented

`lib/EMUSerial-master/` is GTO2013's library, unmodified. The adapter above it
translates its struct into the project's own type but re-scales nothing,
because the dividers in the format file *are* the protocol.

Writing a cleaner decoder was tempting and was not done. The reference
implementation is the specification available.

---

# Open items

- **Which Analog In carries oil pressure and which carries fuel pressure.**
  Not readable from the schematic — the wire routing has no text. Harmless for
  the firmware provided both channels are assigned in the EMU software; if
  they are not, the values arrive only as raw volts on `analogIn1..4`.
- **Extension port pin numbering.** The BT Module manual gives the supply
  rule in text but the pin numbers only in a figure, which could not be read
  out of the PDF. Pin 5 is +5 V and must not be used; the 3.3 V, ground and
  serial pins still have to be read off the manual's drawing and recorded in
  `wiring/signal-list.md` before anything is soldered.
- **The ECUMASTER serial protocol must be enabled** in the EMU Classic Client
  and made permanent, or the port stays quiet.
- **The 1.200/1.211 channel 33 mismatch is moot on EDL-1**, which carries
  `afrTarget` and `scondarypulseWidth` as separate fields at fixed offsets. It
  still applies to the classic environment; see
  [ecu-protocol.md](ecu-protocol.md#version-mismatch-channel-33).
- **160 EDL-1 channels are decoded but not displayed.** Listed in
  [edl-channels.md](edl-channels.md); boost control, knock-versus-noise,
  trigger health and idle control are the ones this car can actually use.
- **The SD card mounts intermittently, and nobody knows why.** Measured on the
  bench: same card, same build, four consecutive resets gave mount, fail,
  mount, fail. Dropping the bus clock from an out-of-spec 80 MHz to 25 MHz
  changed nothing. A later session of eleven consecutive resets all mounted on
  the first attempt with nothing in the firmware to explain the difference -
  most likely the card seating itself, but that is a guess. `EmuLog::begin`
  now retries three times 100 ms apart and reports which attempt worked, so a
  `card mounted on attempt 2` in the console is the signal that the fault is
  back. Vibration in the car is its own test of that contact.
- **The Diag page's latched block is redundant.** The Alarms page supersedes
  it and does it properly. Removing the block frees about 60 px of the left
  column, which the link history would use well.
- **The clock drifts and does not know about daylight saving.** The crystal is
  uncompensated, so expect one to three minutes a month, always slow. Every
  reflash resyncs it; twice a year it is an hour out until one happens.
- **UI repaints at frame rate.** `DashUi` updates the visible page whenever the
  model's revision changes, which at 19200 baud is a few hundred times a
  second. LVGL coalesces the redraw, but the formatting work is done every
  time. Rate-limiting to about 20 Hz would cut it by an order of magnitude and
  make the digits readable rather than a blur.
- **LVGL object pool headroom: closed, the hard way, on 2026-09-19.** This
  entry used to say the pool was "unmeasured, but no longer suspect", and that
  if a page ever came up blank or the dash restarted on the way to one, this
  was the first thing to raise. It restarted on the way to the Limits
  category. `LV_MEM_SIZE` is 128 kB now, SETUP works from a fixed pool of rows
  so it no longer scales with the settings table, and the number is finally
  readable - the service page prints it under Diagnostics. See
  docs/test-results.md.
- **Enclosure dimensions are not verified.** `enclosure/case.scad` is
  parametric and its geometry is right, but the measurements at the top of the
  file are placeholders. They must be taken from Elecrow's STEP model or the
  physical panel before printing.
- **Fonts.** LVGL's built-in Montserrat is not condensed and stops at 48 px,
  so the RPM readout is smaller than the mockup's. `λ` and `Δ` are outside its
  character set, so the UI uses `LAMBDA`, `DFPR` and `C` instead of `°C`. A
  custom font subset would fix all of this at once - and would give the
  three-across pages more than the 36 px they read at now, since a condensed
  face at 44 px would fit the same 144 px cell.
- **Alarm state freezes when the link drops.** Evaluation now runs on a link
  state change as well as on new data - it has to, or a lost link would never
  be recorded as an event - but it re-evaluates the same stale snapshot, so
  the last known severities persist while the status bar reads `OFFLINE`.
  Deliberate for now; clearing them on `Offline` is a small change in
  `DashUi::update`.

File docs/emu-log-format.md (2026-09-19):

# The .emulog file format

What EMU Classic Client writes, how that was established, and what this project
has to do to write a file the Client opens.

This document replaces an earlier one that described a different format
entirely. That earlier description — validated 5-byte classic serial frames
concatenated into a `.emualog` file — was learned from a third-party project and
never verified. It is wrong. Nothing below rests on it.

## The format

```
.emulog = gzip( 12-byte header + N x 256-byte records )
```

**Header**, identical in every sample seen:

| Bytes | Value | Meaning |
|---|---|---|
| 0–3 | `80 60 40 20` | Marker |
| 4–7 | `01 00 00 00` | Version, presumably. Always 1 |
| 8–11 | `80 96 98 00` | 10 000 000 as u32 LE. Purpose unknown |

**Record** — one complete sample, little-endian throughout:

```
record[i] == EDL-1 frame data[i+4]
```

A record is the 260-byte EDL-1 frame with its 4-byte marker `32 40 50 60`
stripped. 260 − 4 = 256. There is no per-record header, no separator, and no
timestamp.

That single line is the whole of it, and it is the reason this became easy: the
channel map already exists in [`lib/EDLSerial/src/EDLSerial.cpp`](../lib/EDLSerial/src/EDLSerial.cpp),
so nothing has to be decoded, assembled, scaled, or looked up to write a log.
The bytes arriving from the ECU are, minus four, the bytes the file wants.

**Compression.** The deflate stream is flushed periodically with `Z_SYNC_FLUSH`
and **never finalised**: no final block, no CRC32, no ISIZE. Both Client-written
samples end exactly on a `00 00 ff ff` flush boundary. This is not corruption,
it is how a logger writes a file it may never get to close. The practical
consequences:

- `gunzip` reports `unexpected end of file` and **silently truncates its
  output**. Use [`tools/emulog_inspect.py`](../tools/emulog_inspect.py), or
  `zlib.decompressobj(31)`, which tolerate it.
- The firmware never has to close a log cleanly. Cutting power loses at most
  the bytes since the last flush.

The gzip header the Client writes is the minimal 10 bytes, `1f 8b 08 00
00000000 00 0b` — no name, no mtime, OS 0x0b.

## The time axis

There are no timestamps in the file. `frameStamp` (`data[4:6]`, so record bytes
0–1) is the ECU's own sample counter, incrementing by 1 per record, and the
Client derives the time axis from it — 0.05 s per count in both samples, i.e.
20 Hz. Since the counter comes from the ECU inside the frame, writing frames
verbatim gets the time axis right for free.

The log's date and time come from the **filename**: `20230519_0615_08.emulog`.
That is the only thing the writer contributes that the ECU does not, and the
only reason logging needs the RTC.

This dashboard splits that name across a folder and a file - `/20260919/
1732_04.emulog` - so a season of logs is navigable on the card. Nothing in the
format sees the difference, and downloading one through the service page puts
the date back into the filename.

## How this was established

Antti supplied two Client-written logs and three CSV exports, two of them the
same log exported with different channel selections. Cross-checking the CSVs
against the byte stream pinned the structure without ambiguity:

- **Record size and alignment.** Record count matched CSV row count exactly in
  both logs — 11 421 and 20 387 rows against 11 422 and 20 388 records, the
  Client's export dropping the first record in each. `(length − 12) mod 256`
  is exactly 0 for both files.
- **The offset relation.** 17 channels — `RPM` `MAP` `TPS` `IAT` `Batt` `VE`
  `IgnAngle` `accEnrich` `wboRI` `wboVS` `wboLambda` `wboAFR` `wboIPMeas`
  `wboIPNorm` `wboHeaterDC` `fuelPressure` `ignSparkCount` `deltaFPR`
  `lambdaTarget` — matched `EDLSerial.cpp`'s field map at `data[i+4]` across all
  20 387 samples, to the CSV's 3-decimal rounding. The channels span record
  offsets 2 to 220, so this is not coincidence.
- **The stripped marker.** The byte sequence `32 40 50 60` occurs **zero** times
  in 5.2 MB of decompressed log.

**Then it was proven by writing one.** A file rebuilt from the same data by an
independent writer — our 10-byte gzip header, raw deflate, `Z_SYNC_FLUSH` every
6 records, no trailer — opens in EMU Classic Client and graphs correctly. The
format is not inferred; it has been produced and read back. Feeding
reconstructed 260-byte frames through `EmuLog`'s exact algorithm reproduces
that file byte for byte, so the firmware's output is validated ahead of the
hardware.

**The first record is an ordinary sample.** The Client's CSV export skips it,
which initially looked like a preamble. It is not: record 0 decodes to
plausible values and its `frameStamp` continues into the sequence. The exporter
simply has no previous sample to measure the first interval against. Nothing
special has to be written at the head of the file.

## What the Client requires

- **gzip is mandatory.** An uncompressed file with a correct header and correct
  records opens *without an error message* and graphs nothing. Note the failure
  mode: the Client does not report a bad file, it shows an empty graph. During
  firmware bring-up, "the Client opened it" proves nothing — the graph has to
  show data.
- A missing gzip trailer is fine; the Client's own files have none.
- A 32 KB deflate window is fine. Our test file used one and compressed better
  than the Client's own output.

## Writing one on the ESP32-S3

miniz's deflate compressor is in the chip's ROM and exported by the linker
script — `tdefl_init`, `tdefl_compress`, `tdefl_compress_buffer` — so it costs
no flash. `TDEFL_SYNC_FLUSH` is supported, and omitting `TDEFL_WRITE_ZLIB_HEADER`
produces the raw deflate that belongs under our own gzip header.
`tdefl_compressor` is 167–320 KB depending on the ROM build, which belongs in
PSRAM. At 20 Hz the input is 4.8 kB/s and the output about 1.3 kB/s — roughly
4.6 MB per hour.

This is what `src/logging/emu_log.cpp` now does. `EdlSerialAdapter` offers each
frame that passes its three framing checks to a `FrameSink` before decoding
anything from it, and `EmuLog` drops four bytes and compresses. Nothing is
decoded on the way into a log, so no decode bug can reach one.

Confirmed on the car on 10 September 2026: logs written by the dashboard open
in EMU Classic Client and read the same as ones the Client recorded itself.

## Still unknown

- **The header's third word**, 10 000 000. Constant in both samples, so it is
  copied verbatim; whether the Client reads it is untested.
- **Whether the filename pattern is required** or merely conventional.
- **Whether the record layout is stable across EMU firmware versions.** Both
  samples are one car on one firmware. The layout is the EDL-1 frame layout, so
  this is really the question of whether that frame changes between versions.

## Licensing

The earlier version of this document carried a GPLv3 attribution to
`danuecumaster/ECUMaster-ESP32-Bluetooth-Dashboard-Logger`, from which a
description of a supposed log format had been taken. That format is not this
one, none of it survives, and the attribution is withdrawn as inapplicable.
Everything here was derived from Antti's own log files and from
`docs/ecu-formats/version1_211.xml`, Ecumaster's own format definition, which
ships with their software.

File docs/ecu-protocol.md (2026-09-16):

# EMU Classic serial protocol

> This describes the **classic** protocol, one channel per 5-byte frame. The
> car runs the **EDL-1** protocol instead: 260-byte frames carrying all 195
> channels at once, and since the classic build was removed that is the only
> protocol in the tree. **Nothing here is built any more** - this file is kept
> as a record of the protocol and of why the decoder behaved as it did, not as
> documentation of code you will find. The EDL-1
> framing and its lack of a checksum are covered in
> [architecture.md](architecture.md) and the
> [decision log](decision-log.md); its channels are listed in
> [edl-channels.md](edl-channels.md).

**This project does not implement the protocol.** It uses
[GTO2013/EMUSerial](https://github.com/GTO2013/EMUSerial), vendored unmodified
in `lib/EMUSerial-master/`, as the reference decoder. This document describes
what that code does, so the behaviour is understandable without reading it —
it is not an independent specification, and nothing here should be
reconstructed from guesswork.

## Link

| | |
|---|---|
| Baud | 19200 |
| Framing | 8N1 |
| Direction | ECU → dash. The dash never transmits. |
| Levels | RS-232 at the ECU, converted by a MAX3232 |

## Frame

Five bytes, one channel value per frame:

| Byte | Meaning |
|---|---|
| 0 | Channel id |
| 1 | Magic, always `0xA3` |
| 2 | Value, high byte |
| 3 | Value, low byte |
| 4 | Checksum |

Checksum is the 8-bit sum of the first four bytes:
`channel + magic + valueH + valueL`.

## Synchronisation

There is no start delimiter. The decoder keeps a rolling five-byte window:
each incoming byte shifts the window up and lands in the last position. When
the byte in the magic position reads `0xA3` **and** the checksum matches, the
window is a valid frame. Anything else is discarded silently and the window
keeps sliding.

This means a corrupt or partial frame costs nothing but is also never
reported — see the liveness caveat below.

## Channel decoding

`lib/EMUSerial-master/src/format/emuFormat.h` carries three parallel tables of
35 entries — channel id, divider, and storage type — plus a table of pointers
into `emu_data_t`. Storage types are unsigned/signed byte and unsigned/signed
16-bit word; 16-bit values are big-endian (`valueH << 8 | valueL`).

A divider of 1 means the value is stored as an integer. Any other divider
means the raw value is divided by it and stored as a `float`. **This is where
engineering units come from** — volts, bar, lambda, degrees — which is why the
adapter above it re-scales nothing.

A channel id that is not in the table is ignored. That is the mechanism by
which a firmware/format-file mismatch degrades: unknown channels vanish rather
than corrupting neighbouring fields.

The tables in this repository are format version 1.200, generated from
`extras/version1_200.xml`. The car runs EMU Classic firmware 1.211.

## Version mismatch: channel 33

Those two versions disagree about exactly one channel, and the dashboard is on
the wrong side of it.

1.200 has a defect: `pulseWidth` **and** `scondarypulseWidth` are both declared
on channel 7. The decoder scans the channel table and takes the first match, so
`scondarypulseWidth` never receives anything and sits at zero for ever.

1.211 fixes that by moving `scondarypulseWidth` to channel 33 — and drops
`afrTarget`, which held channel 33 in 1.200, from the transmitted set. It is
still in the XML, just without a `channel` attribute.

So channel 33 means two different things:

| | channel 33 |
|---|---|
| What the ECU sends (firmware 1.211) | `scondarypulseWidth`, word, ÷62, ms |
| What this firmware decodes (tables 1.200) | `afrTarget`, unsigned byte, ÷10, AFR |

`emu_data.afrTarget` therefore holds the low byte of a secondary injector pulse
width divided by ten. It is meaningless.

**Nothing displays it today**, so nothing on screen is currently wrong. The
Tune page's target comes from `lambdaTarget` on channel 32, which is identical
in both versions. `injPulseWidth2Ms` is not displayed either, and would read
zero regardless.

It is a trap rather than a live fault: the value is wrong and looks plausible,
and would start lying the moment someone puts it on a page.

Adopting 1.211 removes `afrTarget` from the struct, which makes the compiler
flag the one place it is read. AFR target is derivable anyway — lambda target
times 14.7 for petrol. See [ecu-formats/](ecu-formats/).

Nothing else differs. Channels 1-32 and 255 are identical in both versions, and
1.211 adds no new channels at all.

## Liveness

`EMUSerial::checkEmuSerial()` returned `void` and `decodeEmuFrame()` was
private, so there was no frame counter to read. `EmuSerialAdapter` therefore
reported **bytes consumed**, and `EngineDataModel` treated byte activity as
evidence the link was alive. EDL-1 counts real frames, so this caveat no longer
applies to anything that is built.

The consequence is honest to state: line noise on an otherwise dead link would
read as `Online`. In practice a floating RS-232 receiver input is quiet, so
this has not been a problem — but if it ever matters, the fix is a decoder
that reports valid frames, not a change in the model.

## Fields

`emuStruct.h` defines all 35 channels. This car measures a subset; see
[../wiring/signal-list.md](../wiring/signal-list.md) for which sensors are
actually fitted and which channels are therefore meaningless.

## Check-engine bits

The `cel` word is a 16-bit fault bitfield, and Ecumaster names the bits. The
mapping is not in the EMUSerial reference implementation - which is why the
diagnostics page showed bare numbers at first - but it is in Ecumaster's own
format definition, [ecu-formats/version1_211.xml](ecu-formats/version1_211.xml),
as `<paramlist name="checkEngine" bitfield="1">`:

| Bit | Flag | Bit | Flag |
|---|---|---|---|
| 0 | CLT | 6 | EGT ALARM |
| 1 | IAT | 7 | KNOCK |
| 2 | MAP | 8 | FF SENSOR |
| 3 | WBO | 9 | DBW |
| 4 | EGT1 | 10 | FPR |
| 5 | EGT2 | | |

**One inference sits in that table.** The paramlist numbers its entries from 1,
and this maps entry N to bit N-1. The file never says so outright, but it is
the only reading that works: `fuelCorrections` in the same file has sixteen
entries for a sixteen-bit word, so its last entry, value 16, has to mean bit
15. Every other bitfield list in the file fits the same way.

Confirm it on the car rather than trusting it: unplug the intake air
temperature sensor and IAT should be the flag that lights. If the flag one
place along lights instead, the table is off by one.

Bits 11 to 15 have no name in the 1.211 definition. The diagnostics page shows
the raw word alongside the flags, so a bit outside the table is still visible.

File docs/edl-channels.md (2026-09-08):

# Channels the EDL-1 stream adds

Generated by comparing `lib/EDLSerial/src/EDLTypes.h` against what
`src/protocol/edl_serial_adapter.cpp` currently maps onto `EngineSnapshot`,
with group and unit taken from Ecumaster's own
[1.211 definition](ecu-formats/version1_211.xml).

The classic serial protocol carries 34 channels, one per 5-byte frame. The
EDL-1 stream carries 195 in a single 260-byte frame, so everything below
arrives from the same instant as everything else.

**Nothing here is displayed yet.** The adapter maps the same values the classic
one did, so the dashboard behaves identically; this is the menu, not the meal.
`EdlSerialAdapter::frame()` exposes the whole frame for whatever gets picked.

Groups this car has no hardware for - VVT, DBW, Nitrous, ALS, TC, Flex Fuel,
VSS - are listed for completeness and are noise on this engine.

Frame fields: **195**  ·  already on the model: **35**  ·  new: **160**

## Fueling (22)

| Field | Unit | Description |
|---|---|---|
| `VE` | % | — |
| `InjOpeningTime` | ms | Injectors cal. time |
| `fuelCut` | — | Fuel Cut |
| `accEnrichPW` | ms | Acc. Enrichment PW |
| `egoCorrection` | % | EGO Correction |
| `BaroCorr` | % | BARO Correction |
| `iatFuelCorr` | % | IAT Correction |
| `fprCorrection` | % | Fuel pressure delta correction |
| `inj1Trim` | % | Injector 1 trim |
| `inj2Trim` | % | Injector 2 trim |
| `inj3Trim` | % | Injector 3 trim |
| `inj4Trim` | % | Injector 4 trim |
| `inj5Trim` | % | Injector 5 trim |
| `inj6Trim` | % | Injector 6 trim |
| `chargeTemp` | C | Charge temp |
| `secondaryInjDC` | % | Secondary inj. DC |
| `secondaryInjSplit` | % | Secondary injectors split |
| `decEnrichPW` | ms | Dec. Enrichment PW |
| `fuelCorrections` | — | Fuel corrections |
| `fcProbability` | % | Fuel cut probability |
| `fuelUsage` | l/h | Fuel usage |
| `injectionAngle` | deg | Injection angle |

## Other (21)

| Field | Unit | Description |
|---|---|---|
| `pidPTerm` | — | Debug PID P Term |
| `pidITerm` | — | Debug PID I Term |
| `pidDTerm` | — | Debug PID D Term |
| `pwmOutputDC` | % | PWM #1 DC |
| `parametricOutput1` | — | Param. Output #1 |
| `parametricOutput2` | — | Param. Output #2 |
| `parametricOutput3` | — | Param. Output #3 |
| `parametricOutput4` | — | Param. Output #4 |
| `pitLimiterActive` | — | Pit limiter active |
| `pitLimiterTorqueReduction` | % | Pit Limiter torque reduction |
| `canBUSState` | — | CAN-Bus State |
| `canBUSSwitech` | — | CAN ext. switches |
| `RPM2nd` | RPM | RPM 2nd engine |
| `muxSwitch` | — | MUX switch state |
| `canSwitch` | — | CAN Switch state |
| `acPressure` | kPa | AC Pressure |
| `acClutch` | — | AC Clutch |
| `acEvap` | C | AC EVAP temp. |
| `miscOutputs` | — | Misc outputs |
| `miscFlags` | — | Misc flags |
| `mswitchState` | — | Momentary sw. state |

## Ignition (14)

| Field | Unit | Description |
|---|---|---|
| `dwellError` | ms | Dwell Error |
| `overdwell` | — | Overdwell |
| `iatIgnTrim` | deg | IAT Ignition Trim |
| `cltIgnTrim` | deg | CLT Ignition Trim |
| `ignFromTable` | deg | Ignition From Table |
| `ignSyncStatus` | — | Trigger sync status |
| `ignError` | — | Trigger error |
| `camSyncPrimTooth` | — | Cam sync trigger tooth |
| `camSyncPresent` | — | Cam signal present |
| `accIgnCorr` | % | Acc. Ignition Correction |
| `cam2Present` | — | Cam #2 signal present |
| `sparkCutPercent` | % | Spark cut percent |
| `ignSparkCount` | — | Executed sparks count |
| `ignCorrections` | — | Ignition corrections |

## Debug (11)

| Field | Unit | Description |
|---|---|---|
| `frameStamp` | — | — |
| `debugUnused` | C | — |
| `ignDTH` | — | — |
| `ignDTL` | — | — |
| `mainLoopSpeed` | ms | — |
| `profiler` | ms | — |
| `debugW` | — | — |
| `reserved1b` | deg | reserved1b |
| `reserved2` | deg | reserved2 |
| `reserved3` | deg | reserved3 |
| `reserved4` | deg | reserved4 |

## LC, Gear cut, FS (10)

| Field | Unit | Description |
|---|---|---|
| `lcActive` | — | LC Active |
| `lcIgnRetard` | deg | LC Ign. Retard |
| `lcFuelEnrich` | % | LC Fuel Enrichment |
| `flatShiftActive` | — | Flat Shift Active |
| `flatShiftCutSpark` | — | Flat Shift Ign. Cut |
| `flatShiftCutFuel` | — | Flat Shift Fuel Cut |
| `ralTarget` | RPM | Rolling anti lag target |
| `ralIgnition` | deg | Rolling anti lag ign. retard |
| `ralActive` | — | Rolling anti lag active |
| `gcActive` | — | Gear cut active |

## Flex Fuel (10)

| Field | Unit | Description |
|---|---|---|
| `flexFuelFrequency` | Hz | FF Sensor frequency |
| `ffBlendVE` | % | FF Blend VE |
| `ffBlendIgn` | % | FF Blend IGN |
| `ffBlendAFR` | % | FF Blend AFR |
| `ffBlendBoost` | % | FF Blend Boost |
| `ffTempFuelCorr` | % | FF Fuel Temp Correction |
| `ffBlendCrankingFuel` | % | FF Blend Cranking Fuel |
| `ffBlendWarmup` | % | FF Blend Warmup |
| `ffBlendASE` | % | FF Blend ASE |
| `ffFuelScale` | % | Ethanol fuel scale |

## Boost (8)

| Field | Unit | Description |
|---|---|---|
| `boostDC` | % | Boost DC |
| `boostDCFromTable` | % | Boost DC From Table |
| `boostTarget` | kPa | Boost Target |
| `boostCorrection` | % | Boost Correction |
| `boostTableSet` | — | Boost Table set |
| `boostTargetFromTable` | kPa | Boost Target From Table |
| `boostPIDCorrection` | % | Boost DC PID Correction |
| `boostDCErrCor` | — | Boost DC error correction |

## Idle (7)

| Field | Unit | Description |
|---|---|---|
| `idleTarget` | RPM | Idle Target |
| `idleDC` | % | Idle Valve DC |
| `idleStep` | step | Idle Motor Step |
| `idleAngleCorr` | deg | Idle Ign. Correction |
| `idleControlActive` | — | Idle Control Active |
| `curentPIDCorrection` | — | Idle PID DC Correction |
| `idleIgnCutPercent` | % | Idle ign. cut percent |

## VVT (7)

| Field | Unit | Description |
|---|---|---|
| `cam1Angle` | deg | CAM1 angle |
| `cam2Angle` | deg | CAM2 angle |
| `cam1ValveDC` | % | CAM1 valve DC |
| `cam2ValveDC` | % | CAM2 valve DC |
| `cam1AngleTarget` | deg | CAM1 angle target |
| `cam2AngleTarget` | deg | CAM2 angle target |
| `vtecOn` | — | VTEC Active |

## DBW (7)

| Field | Unit | Description |
|---|---|---|
| `etcDC` | % | DBW Out. DC |
| `etcTarget` | % | DBW target |
| `etcPos` | % | DBW pos |
| `etcError` | — | DBW error |
| `etcDeltaError` | — | DBW delta error |
| `dbwPotError` | V | DBW Pot error |
| `etcFrictionCorr` | — | DBW friction corr. |

## Enrichments (5)

| Field | Unit | Description |
|---|---|---|
| `TPSRate` | %/s | TPS Rate |
| `Warmup` | % | Warmup enrichment |
| `ase` | % | Afterstart Enrichment |
| `accEnrich` | % | Acc. Enrichment |
| `decEnrich` | % | Dec. Enrichment |

## Knock Sensing (5)

| Field | Unit | Description |
|---|---|---|
| `knockValue` | V | Knock Sensor value |
| `engineNoise` | V | Knock Engine Noise |
| `knockFuelEnrich` | % | Knock Action Fuel Enrich. |
| `knockIgnRetard` | deg | Knock Action Ign. Retard |
| `knockBits` | — | Knock ignition event |

## WBO (5)

| Field | Unit | Description |
|---|---|---|
| `wboRI` | V | WBO RI |
| `wboHeaterDC` | % | WBO Heater DC |
| `wboVS` | V | WBO VS |
| `wboIPMeas` | mA | WBO IP Meas. |
| `wboIPNorm` | mA | WBO IP Norm. |

## Analog inputs (5)

| Field | Unit | Description |
|---|---|---|
| `tpsVoltage` | V | TPS Voltage |
| `CANain1` | V | CAN Analog #1 |
| `CANain2` | V | CAN Analog #2 |
| `CANain3` | V | CAN Analog #3 |
| `CANain4` | V | CAN Analog #4 |

## Timers (5)

| Field | Unit | Description |
|---|---|---|
| `timer1` | sec | Timer 1 |
| `timer2` | sec | Timer 2 |
| `timerFuelEnrich` | % | Timer fuel corr. |
| `timerBoostCorr` | % | Timer boost corr. |
| `timerIgnCorr` | deg | Timer ign. corr. |

## Nitrous (4)

| Field | Unit | Description |
|---|---|---|
| `nitrousActive` | — | Nitrous Active |
| `nitrousIgnMod` | deg | Nitrous ign. mod. |
| `nitrousFuelScale` | % | Nitrous fuel scale |
| `nitrousFuelAdder` | ms | Nitrous fuel adder |

## ALS (4)

| Field | Unit | Description |
|---|---|---|
| `alsActive` | — | ALS Active |
| `alsIgnAngle` | deg | ALS igntion angle |
| `alsSparkCut` | % | ALS spark cut |
| `alsFuelCorr` | % | ALS fuel correction |

## TC (4)

| Field | Unit | Description |
|---|---|---|
| `tcdRPM` | RPM | TC dRPM |
| `tcdRPMRaw` | RPM | TC dRPM Raw |
| `tcTorqueReduction` | % | TC Torq. Reduction |
| `tcAdjPos` | — | TC adjust pos |

## Basic (3)

| Field | Unit | Description |
|---|---|---|
| `EMUState` | — | ECU State |
| `wasReset` | — | ECU Reset |
| `gearBoxOilTemperature` | C | Gearbox oil temperature |

## Vss and gears (3)

| Field | Unit | Description |
|---|---|---|
| `vssFreq` | Hz | VSS Frequency |
| `gearRatio` | — | Gear Ratio |
| `shiftLightOn` | — | Shift Light On |

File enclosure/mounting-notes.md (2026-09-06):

# Mounting notes

## Where the dimensions come from

Elecrow publishes the panel's mechanical model. It is the authoritative source
— this repository does not restate the numbers, because a transcribed
dimension that is wrong costs a print.

In the
[Elecrow-RD demo repository](https://github.com/Elecrow-RD/CrowPanel-Advance-3.5-HMI-ESP32-S3-AI-Powered-IPS-Touch-Screen-480x320):

| Path | What it is |
|---|---|
| `3D file/advance-hmi3_5-20260126.stp` | Panel assembly, STEP, ~6 MB |
| `3D file/00-35-_asm.stp` | Full assembly, STEP, ~39 MB |
| `Eagle_SCH&PCB/` | Board files — mounting hole positions |

Open the STEP in any CAD tool (FreeCAD is free and reads it) and measure:

1. Overall outline of the panel assembly, X and Y
2. Depth from the glass face to the tallest component on the back
3. Mounting hole diameter, and their positions from one corner
4. Glass active-area rectangle relative to that same corner
5. USB-C and UART connector positions along their edges

Those five measurements are exactly the parameters at the top of
[`case.scad`](case.scad). Fill them in and the model is complete.

> **The values currently in `case.scad` are placeholders.** They are marked as
> such in the file. Do not print until they have been replaced with measured
> numbers — the geometry is right, the dimensions are not.

The STEP file was inspected while writing this, but its point cloud is in
per-part local coordinates without the assembly transforms applied, so a
bounding box taken from it is meaningless. There is no shortcut around opening
it in CAD or measuring the physical panel with calipers.

## Mounting in the car

Decide the location before finalising the case, because it sets the exit angle
of both cables.

Points worth thinking through:

- **Sight line.** The screen should fall inside the driver's normal scan
  without obscuring the road or the original instruments.
- **Airbag paths and trim.** Nothing rigid in a deployment path.
- **Cable strain relief.** Both cables need a fixed anchor within ~100 mm of
  the case so vibration works against the anchor, not the connector.
- **Serviceability.** The USB-C port has to stay reachable for flashing with
  the case mounted.
- **Removal.** A dashboard-mounted screen is worth stealing. A mount that
  detaches without tools is a feature.

## Record here once decided

- Mount location and fixing method
- Cable routing from the case to the EMU extension port
- Where the MAX3232 sits inside the case, and how it is retained

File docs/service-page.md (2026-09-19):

# Service page

The dashboard raises a WiFi access point while the engine is stopped and serves
a maintenance page on it. The logs are read on the tuning laptop, which comes to
the car anyway, so they go to it directly rather than through anywhere else.

## Joining

| | |
| --- | --- |
| SSID | `EcuDash` |
| Password | `ecudash1` (WPA2) |
| Address | `http://192.168.4.1/` |

These are compile-time constants in `include/service_config.hpp`. The panel has a
plus and a minus button and cannot enter text, so they are not editable there.

The network and the key are also shown on the dashboard's own **DIAG** page,
under the peaks, so they can be read while standing beside the car rather than
looked up. The network name turns green and gains a count once a laptop has
actually joined - which is the difference between "the radio is up" and "I am
on it". The address is not shown there: it is always `192.168.4.1`, and the page
had room for two rows.

The status bar carries the short form on every page: `WIFI`, or `WIFI 1` once
someone has joined. It is blank whenever the radio is off, which is whenever the
car is moving.

## When the access point is up

Turn `Service AP` on under `Log` on the setup page - it is off by default,
because a radio that comes up on its own in a parked car should be asked for.

Then all of these have to hold:

- the engine is stopped: engine speed below the running threshold, or the ECU
  link silent, continuously for ten seconds;
- battery voltage at or above 12.0 V, tested only while the ECU is still
  reporting - with the link quiet there is no reading to test, and refusing on a
  value we do not have would mean the access point never appearing with the
  ignition off.

It goes down again the moment the engine starts, if the voltage falls below the
floor, or after fifteen minutes with nobody connected. Once it has gone down for
idleness it stays down until the engine runs again: a parked car gets one window
per drive rather than a radio that cycles all night.

## Why the engine has to be stopped

With the engine off the ECU sends nothing, so nothing is written to the card
while the server reads from it. That is what keeps the whole feature inside the
existing cooperative loop: no second task, no mutex, no card shared between two
cores. The one failure mode that would actually matter - a corrupted log -
cannot arise.

It also means the live channel view that would help most when chasing a decoder
bug is not possible here, since there is no data to show. That is the trade.

## The page

**Logs.** Every `.emulog` on the card with its size and a checkbox, grouped
under the day it was recorded. The dashboard writes each day into its own
folder - `/20260919/1732_04.emulog` - because the engine stopping rotates the
file, so a tuning day is a dozen of them and a season is several hundred. The
day's heading carries its own checkbox, which is how a whole day is taken or
dropped in one go.

Logs left in the card's root from before this are still listed, under a
heading of their own, and work exactly as they did.

One selected file downloads as itself, with its day folded into the name so
the laptop's download folder does not end up holding six files called
`1732_04.emulog`. Several come down as a single `.tar`, uncompressed because
the files are already gzip, named for the moment it was fetched -
`emulogs_20260919_1732.tar` - and holding the day folders, so unpacking it
reproduces the card's layout. The file currently being written is listed but
cannot be selected or deleted - it is still open.

Deleting asks first and names what it is about to remove. There is no "delete
everything" form: the page confirms a list and the server acts on that list.

**Name the next drive.** Text appended to the next log file's name, so a tuning
day's runs can be told apart. Anything outside `[A-Za-z0-9_-]` is replaced.

**Settings.** Changes apply to the dashboard the moment the server accepts them
- the page writes into the same `DashSettings` the panel edits, then the owner
re-applies alarm limits and brightness and repaints the SETUP page's rows. The
flash write is debounced by four seconds after the last edit, the same as a held
button on the panel, so a change made and then powered off inside four seconds is
lost. The value that comes back from the server is the clamped one and may differ
from what was typed.

The same fields the panel edits, generated from the shared table in
`include/setup_items.hpp`, clamped by the same ranges and applied through the
same path. Neither editor can drift from the other, and neither is a way around
the rule that only numbers and switches are editable - which value an alarm
watches stays in code. Fields differing from the built-in defaults are marked.

**Diagnostics.** What `announce()` prints to a console nobody can reach in a car,
plus the clock. The dashboard has no network and no GPS, so its clock is seeded
from the build stamp and drifts; one button sets it from the browser's own clock,
which needs no internet and is right to about a second.

**Alarms.** The event log, newest first - what tripped, when, and at what engine
speed. Unavailable if the display failed to come up, since the alarm engine lives
with the UI; the page says so rather than showing an empty list that would look
like a clean run.

## Browsers

The page needs `fetch` and `Promise`, which arrived in Edge 14, and CSS custom
properties, which arrived in Edge 15. Everything is fetched, so a browser
without them has nothing to show.

- **Anything current** - Chromium-based, Firefox, Safari - works.
- **Edge Legacy** (the pre-Chromium Edge on older Windows 10) worked only after
  the `NodeList.forEach` calls were removed; it does not have that method, and
  the throw happened before the first fetch, leaving a page with no data in it.
  The script is plain ES5 now and avoids it.
- **Internet Explorer** renders the markup and nothing else. It has no CSS
  custom properties, so all 68 of the page's colours are invalid, and no fetch,
  so no data arrives. It is not worth supporting and is not supported.

A browser that cannot run the page now says so in red at the top instead of
sitting there looking empty, and any script error is shown the same way.

## Notes for whoever changes this

- The page is one PROGMEM string in `src/web/service_page_html.cpp`. This network
  has no route to the internet, so nothing can be loaded from a CDN: all the CSS
  and script live in that string, and system fonts do the typography.
- Writes are POSTs and are refused with 409 while the engine is running. That
  cannot happen anyway - the access point is down by then - but the server does
  not rely on that to be safe.
- Downloads run LVGL between blocks (`ServiceContext::pump`), so the screen shows
  progress instead of freezing for the length of the transfer.
- Filenames from the client are checked against `safeName()` before anything is
  opened: a `.emulog` suffix, no `..`, and either no slash at all or exactly
  one, preceded by eight digits. A request cannot name a folder this dashboard
  did not create.
- "Is the engine running", for the 409, is `engineStopped()` and not the rpm
  field. Cutting the ignition cuts the ECU's power mid-frame, so the snapshot
  keeps reporting the last rpm it ever saw; read on its own it says "running"
  in a parked car, and it refused every delete and every setting change on 19
  September 2026 until the dashboard was rebooted.
- A refusal's own text is what the page shows. It used to read the 409 as JSON,
  throw, and report "the dashboard refused the request", which said nothing
  about which of the two reasons it was.
- The log listing is sent in chunks rather than built whole. A card holding a
  season of logs is tens of kilobytes of JSON, and that much heap held while
  the radio is up is heap the radio wanted.

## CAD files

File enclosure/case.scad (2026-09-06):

// Enclosure for the ECU dashboard
// CrowPanel Advance 3.5" HMI + MAX3232, cabin-mounted in a Toyota Carina.
//
// Two printed parts, screwed together:
//   front  - bezel, screen opening, panel standoffs
//   back   - shell, vents, MAX3232 bay, cable exits
//
// Render one part at a time with the `part` variable below, or "both" for a
// preview of the assembly.
//
// ---------------------------------------------------------------------------
//  READ THIS BEFORE PRINTING
//
//  Every value in the MEASURE block is a PLACEHOLDER. The geometry in this
//  file is correct; the numbers are not. Elecrow does not publish a dimension
//  table, and the STEP model's coordinates cannot be reduced to a bounding box
//  without a CAD kernel.
//
//  Take the five measurements listed in mounting-notes.md from
//  3D file/advance-hmi3_5-20260126.stp, or with calipers from the panel
//  itself, and replace them here. Nothing else needs to change.
// ---------------------------------------------------------------------------

part = "both";   // "front" | "back" | "both"

$fn = 48;

// ===========================================================================
//  MEASURE  -  placeholders, replace with real numbers
// ===========================================================================

// Panel assembly outline, looking at the glass.
panel_w      = 100.0;   // PLACEHOLDER  width
panel_h      =  70.0;   // PLACEHOLDER  height
panel_d      =  14.0;   // PLACEHOLDER  glass face to tallest rear component

// Glass active area, measured from the panel's bottom-left corner.
glass_x      =  13.0;   // PLACEHOLDER
glass_y      =  10.0;   // PLACEHOLDER
glass_w      =  74.0;   // PLACEHOLDER  480 px at 3.5" diagonal is ~73 mm
glass_h      =  49.0;   // PLACEHOLDER  320 px                     ~49 mm

// Panel mounting holes: four, inset from each corner.
hole_dia     =   2.6;   // PLACEHOLDER  M2.5 clearance
hole_inset_x =   3.5;   // PLACEHOLDER
hole_inset_y =   3.5;   // PLACEHOLDER

// Connector cut-outs. `pos` is measured along that edge from the
// bottom-left corner; `z` is height above the rear face of the panel.
usb_pos      =  50.0;   // PLACEHOLDER  USB-C, bottom edge
usb_w        =  12.0;   // PLACEHOLDER
usb_h        =   8.0;   // PLACEHOLDER

uart_pos     =  20.0;   // PLACEHOLDER  UART1-OUT connector, right edge
uart_w       =  14.0;   // PLACEHOLDER
uart_h       =   9.0;   // PLACEHOLDER

// MAX3232 breakout, housed inside the back shell.
max_w        =  22.0;   // PLACEHOLDER
max_h        =  16.0;   // PLACEHOLDER
max_d        =   8.0;   // PLACEHOLDER

// ===========================================================================
//  Design parameters  -  safe to tune
// ===========================================================================

wall         =   2.4;   // 3 perimeters at 0.4 mm plus a margin
bezel        =   2.0;   // how far the front face overlaps the glass edge
                        // keep small: a capacitive digitiser reads to the edge
fit          =   0.35;  // clearance around the panel, per side
standoff_h   =   1.6;   // lifts the panel off the front face
corner_r     =   3.0;
screw_dia    =   3.2;   // M3 clearance in the front
insert_dia   =   4.2;   // heat-set insert in the back
tilt         =  12;     // degrees the face leans back toward the driver

vent_w       =   2.0;
vent_gap     =   3.5;

// ---------------------------------------------------------------------------

cav_w = panel_w + 2 * fit;
cav_h = panel_h + 2 * fit;
out_w = cav_w + 2 * wall;
out_h = cav_h + 2 * wall;
front_d = standoff_h + wall;
back_d  = panel_d + max_d + 2 * wall;

module rrect(w, h, d, r) {
    hull()
        for (x = [r, w - r], y = [r, h - r])
            translate([x, y, 0]) cylinder(r = r, h = d);
}

// The four panel screw positions, in panel coordinates.
module at_holes() {
    for (x = [hole_inset_x, panel_w - hole_inset_x],
         y = [hole_inset_y, panel_h - hole_inset_y])
        translate([wall + fit + x, wall + fit + y, 0]) children();
}

// Case screws sit outside the panel, in the corners of the shell.
module at_screws() {
    for (x = [wall / 2 + 1.5, out_w - wall / 2 - 1.5],
         y = [wall / 2 + 1.5, out_h - wall / 2 - 1.5])
        translate([x, y, 0]) children();
}

// ===========================================================================
//  Front
// ===========================================================================

module front() {
    difference() {
        union() {
            rrect(out_w, out_h, front_d, corner_r);
            // standoffs the panel rests on
            at_holes()
                cylinder(d = hole_dia + 3.2, h = front_d + standoff_h);
        }

        // screen opening, inset by the bezel overlap on every side
        translate([wall + fit + glass_x + bezel,
                   wall + fit + glass_y + bezel,
                   -1])
            cube([glass_w - 2 * bezel, glass_h - 2 * bezel, front_d + 4]);

        // panel screws pass through
        at_holes() translate([0, 0, -1])
            cylinder(d = hole_dia, h = front_d + standoff_h + 4);

        // case screws, countersunk from the face
        at_screws() {
            translate([0, 0, -1]) cylinder(d = screw_dia, h = front_d + 4);
            translate([0, 0, -0.01]) cylinder(d1 = screw_dia + 3, d2 = screw_dia, h = 1.8);
        }
    }
}

// ===========================================================================
//  Back
// ===========================================================================

module back() {
    difference() {
        rrect(out_w, out_h, back_d, corner_r);

        // hollow
        translate([wall, wall, -1])
            cube([cav_w, cav_h, back_d - wall + 1]);

        // USB-C, bottom edge - stays reachable for flashing
        translate([wall + fit + usb_pos - usb_w / 2, -1, wall])
            cube([usb_w, wall + 2, usb_h]);

        // ECU cable, right edge
        translate([out_w - wall - 1, wall + fit + uart_pos - uart_w / 2, wall])
            cube([wall + 2, uart_w, uart_h]);

        // vents: back face only, never the top edge
        for (i = [0 : floor((cav_h - 20) / vent_gap)])
            translate([out_w * 0.25, wall + 10 + i * vent_gap, back_d - wall - 1])
                cube([out_w * 0.5, vent_w, wall + 2]);

        // heat-set inserts for the case screws
        at_screws() translate([0, 0, back_d - wall - 6])
            cylinder(d = insert_dia, h = 8);
    }

    // MAX3232 bay: a shelf with two retaining walls, behind the panel
    translate([wall + 3, wall + 3, back_d - wall - max_d]) {
        difference() {
            cube([max_w + 2 * 1.6, max_h + 2 * 1.6, 1.6]);
            translate([1.6, 1.6, -1]) cube([max_w, max_h, 4]);
        }
        cube([1.6, max_h + 2 * 1.6, max_d]);
        translate([max_w + 1.6, 0, 0]) cube([1.6, max_h + 2 * 1.6, max_d]);
    }
}

// ===========================================================================
//  Render
// ===========================================================================

if (part == "front") front();
else if (part == "back") back();
else {
    // preview: front laid flat, back beside it, tilt shown on the front only
    rotate([tilt, 0, 0]) front();
    translate([out_w + 15, 0, 0]) back();
}

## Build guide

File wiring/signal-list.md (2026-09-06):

# Signal list — ECU to dashboard

Sources:

- Car loom: `Carina_1GGTE_Ecumaster_rev16.pdf`
- ECU port: [Ecumaster BT Module manual](https://www.ecumaster.com/files/Manuals/BT_Module_Manual.pdf), document version 1.1

## The link: EMU Classic extension port → MAX3232 → ESP32-S3

The dashboard **replaces the Ecumaster BT Module** and plugs into the same
place: the EMU Classic's extension port. That port carries the ECU's serial
output and its own supply.

The port speaks **RS-232 voltage levels** — nominally ±5 to ±15 V, idling
*negative*. An ESP32-S3 GPIO is a 3.3 V input and would be destroyed by that
directly, so a MAX3232 converts between the two.

```
  EMU Classic                MAX3232                    ESP32-S3
  extension port

  serial out ───RS-232──▶  R1IN ───▶ R1OUT ──3.3 V TTL──▶  GPIO18  (UART1 RX)
                           T1OUT ◀── T1IN  ◀──────────────  GPIO17  (UART1 TX)

  3.3 V  ─────────────────▶ VCC          ← the ECU powers the level shifter
  GND    ─────────────────▶ GND  ─────────────────────────  dash ground
  +5 V   ── DO NOT CONNECT
```

### Supply: 3.3 V from the ECU, never 5 V

The MAX3232 takes its power from the extension port, not from the panel. The
BT Module manual is explicit about that port, and the warning transfers
directly to anything else plugged into it:

> The module is designed to operate at 3.3 V supply voltage only.
> Pin 5 (+5 V) must not be used.
> Applying 5 V may result in permanent damage to the device.

Two things follow, and both are easy to get wrong:

- **Leave the +5 V pin unconnected.** It is present on the port and it is not
  the supply.
- **Do not tie the ECU's 3.3 V to the panel's 3.3 V.** The MAX3232 is powered
  from one rail only — the ECU's. Bridging two independently regulated 3.3 V
  rails invites current to flow between them. **Only the grounds are common**,
  and they must be, or RS-232 signalling has no reference.

The MAX3232's TTL-side output swings to whatever VCC it is given, which is why
the supply voltage decides whether the ESP32 survives: from 3.3 V it drives a
3.3 V logic level into GPIO18, which is correct.

One consequence of powering from the ECU: with the ignition off the level
shifter is unpowered even if the dash is running on USB. The dash simply reads
`OFFLINE`, which is the honest state.

### The TX line

GPIO17 is wired through to the port and assigned in `board_config.hpp`,
because that is the configuration the link was actually verified with.

**It is never driven.** No code in this project writes to the ECU port — the
provider and the adapter are the only files that touch it, and neither calls
`write()`. The manual also describes the port as one-way:

> Data transmission: One-way (ECU → external device)

So the TX line is present but idle. If you ever want the hardware guarantee
back instead of the software one, set `board::kEcuTxPin` to `-1` and the pin
is never attached to the UART at all.

### Practical notes

- **Module silkscreens lie.** On breakout boards "RXD" sometimes labels the
  TTL side and sometimes the RS-232 side. Trust the function, not the label:
  the pin going to the ECU must be an *RS-232 input* (R1IN), and the pin going
  to GPIO18 must be a *TTL output* (R1OUT). If you get no data, this is the
  first thing to swap.
- **No inversion is needed in software.** RS-232 idles low-true; the MAX3232
  receiver hands the UART a normal idle-high TTL stream, so `SERIAL_8N1` is
  correct as-is.
- **Charge-pump capacitors.** The MAX3232 generates its ±RS-232 rails
  internally and needs four external capacitors (typically 100 nF) on C1±,
  C2±, V+ and V−. Ready-made modules already have them; a bare chip does not.
- **Enable the stream in the ECU.** The EMU Classic Client has to have the
  *ECUMASTER serial protocol* switched on, then the change made permanent
  ("Make permanent" on the toolbar). Without it the port stays quiet.

### Link parameters

| | |
|---|---|
| Baud | 19200 |
| Framing | 8N1 |
| Direction | ECU → dash. The dash never transmits. |
| Dash RX | GPIO18 (UART1-OUT connector RX) |
| Dash TX | GPIO17 — wired and assigned, never driven |
| Level shifter supply | 3.3 V from the EMU extension port |

### To fill in: extension port pin numbering

The manual states the supply rule in text but gives the pin numbering only in
a figure, which could not be read from the PDF as text. **Pin 5 is +5 V and
must not be used** — that much is written out. The pins carrying 3.3 V, ground
and the serial lines have to be read off the manual's connector drawing before
anything is soldered.

Record them here once confirmed.

## ECU sensor inputs (EMU Classic connector B)

What the car actually has, read from the schematic. This is what decides which
channels the dashboard displays.

| Pin | Signal | Sensor |
|---|---|---|
| B1 | EGT In #1 | Marked *(optio)* — **not fitted** |
| B2 | Knock Sensor In #1 | Knock sensor #1 |
| B3 | Analog In #2 | see below |
| B4 | CLT In | Coolant temperature |
| B5 | WBO Vs | Wideband lambda |
| B6 | Camsync In #2 | |
| B7 | Primary trigger In | VR crank sensor |
| B9 | EGT In #2 | Marked *(optio)* — **not fitted** |
| B10 | Knock Sensor In #2 | Knock sensor #2 |
| B11 | Analog In #3 | see below |
| B12 | TPS In | Throttle position |
| B13 | WBO Ip | Wideband lambda |
| B14 | VSS In | **Not fitted** |
| B15 | Camsync #1 | |
| B17 | ECU Ground | |
| B18 | Sensor Ground | |
| B19 | Analog In #4 | see below |
| B20 | Analog In #1 | see below |
| B21 | IAT In | Intake air temperature |
| B23 | +5 V supply | Sensor supply |
| B24 | Power Ground | |

Two three-wire pressure senders are fitted — **oil pressure, 200 psi** and
**fuel pressure, 100 psi** — each on one of the four analog inputs. Which
sender sits on which input could not be read from the schematic, because the
wire routing is drawn as plain lines with no text. It does not affect the
firmware: the EMU fills `oilPressure` and `fuelPressure` directly, provided
both channels are assigned in the EMU software. If those assignments are
missing, the values arrive only as raw volts on `analogIn1..4`.

MAP and barometric pressure come from the EMU's internal sensor; there is no
external MAP sensor in the loom.

### Channels the ECU streams but this car cannot measure

Oil temperature, fuel level, flex-fuel ethanol content and its temperature,
gear position, vehicle speed, and both EGT channels. The ECU sends them
regardless; the dashboard shows none of them.

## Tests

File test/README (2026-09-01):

This directory is intended for PlatformIO Test Runner and project tests.

Unit Testing is a software testing method by which individual units of
source code, sets of one or more MCU program modules together with associated
control data, usage procedures, and operating procedures, are tested to
determine whether they are fit for use. Unit testing finds problems early
in the development cycle.

More information about PlatformIO Unit Testing:
- https://docs.platformio.org/en/latest/advanced/unit-testing/index.html

#include <EMUSerial.h>
EMUSerial emu(Serial1);

void setup()
{
	Serial.begin(19200); //Debugging
	Serial1.begin(19200, SERIAL_8N1, 16, 17); //EMU Serial setup, 8 Data Bits 1 Stopbit, RX Pin, TX Pin
}

void loop()
{
	emu.checkEmuSerial();

	Serial.println(emu.emu_data.MAP); //uint16_t
	Serial.println(emu.emu_data.Batt); //float  
    delay(500);
}

#include <Arduino.h>

HardwareSerial ecuSerial(2);

void setup()
{
    Serial.begin(19200);

    ecuSerial.begin(
        19200,
        SERIAL_8N1,
        16, // RX
        17  // TX
    );

    Serial.println();
    Serial.println("HEX monitor started");
}

void loop()
{
    while (ecuSerial.available())
    {
        uint8_t b = ecuSerial.read();

        if (b < 0x10)
            Serial.print('0');

        Serial.print(b, HEX);
        Serial.print(' ');
    }
}

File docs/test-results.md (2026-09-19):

# Test results

Newest first. Record what was actually observed, not what was expected — an
entry that only says "worked" is worth very little later.

---

## 2026-09-19 — second service-page session, three defects

Observed by using the dashboard, all three fixed in this session. The logs page
itself worked well: the listing, the downloads and opening the files in the
Client all behaved.

- **The SETUP page rebooted the dashboard on the Limits category.** Opening it
  panicked and restarted the board, every time, with nothing printed. The cause
  is LVGL's fixed pool: `lv_obj_create` returns NULL when it is full and LVGL
  then dereferences that NULL one call later, with no assert and no log, so an
  out-of-memory looks exactly like a wild pointer. Limits is eighteen rows of
  about eight objects each, built in one go, and the IDLE and BOOST pages added
  on 2026-09-14 had taken enough of the pool to put it over. The rows are a
  fixed pool of eight now, re-labelled rather than rebuilt, so the page costs
  the same whatever is on it; `LV_MEM_SIZE` went from 96 to 128 kB for margin,
  and what is left of the pool is on the service page's Diagnostics tab.

  The run on 2026-09-08 listed "whether the LVGL object pool holds the Limits
  category" as a thing to check. It did not.

- **Every write the service page accepts was refused.** Deleting a log said
  "the dashboard refused the request"; changing a limit or enabling an alarm
  failed the same way. Both are the 409 from `writable()`, which asked
  `snapshot().rpm >= kEngineRunningRpm` with no regard for the link. Killing
  the ignition cuts the ECU's power mid-frame, so the snapshot holds the last
  rpm it ever saw - the same freeze the engine-off summary was fixed for on
  2026-09-08 - and the dashboard spent the whole session believing an engine
  that had been idling at 850 rpm was still running. It uses `engineStopped()`
  now, which both this and the access point read from one place.

  It had worked before because it depends on how the car was shut down: with
  the ECU still powered, the last frame says 0 rpm.

- **The refusal did not say why.** The page read the 409's plain text as JSON,
  which threw, and reported a generic refusal - so the one message that would
  have named the cause was thrown away. Every write now shows what the server
  actually said.

Added in the same session, both asked for after living with the logs:

- Logs are written into a folder per day, `/20260919/1732_04.emulog`. Files
  already in the root are left there and still listed.
- The multi-file `.tar` is named for the moment it was fetched, since a tuning
  day means fetching several.

### Worth checking on the next run

- SETUP: that the Limits and Alarms categories open, that a swipe up and down
  walks a long category, and - the thing this page lost when it stopped being
  an LVGL scroller - that a vertical swipe starting on a `+` or `-` does not
  land as a press on it.
- Deleting a log, now that it can be reached at all, and that the day's folder
  disappears with its last file.
- That the dashboard still has heap to spare with the radio up: the service
  page reports free heap and the LVGL pool side by side under Diagnostics.

Added afterwards, from the same session's look at the panel: the readings on
the three-across pages went 28 px to 36 px, the unit moved up beside the
caption so a wide reading cannot run into it, captions went yellow, and the
status bar was rebuilt as fixed slots. None of it is on the car yet. What to
look at: whether 36 px is enough at arm's length in daylight, whether any
reading overflows its cell - the widths were checked against the font's own
metrics, but only for the values the ECU has actually been seen to send - and
whether the status bar still reads cleanly with an alarm latched and the
access point up at the same time, which is the case that overlapped.

---

## 2026-09-16 — service page, first run on the car

Working on the hardware, observed: the access point comes up once `Service AP`
is switched on in Setup (it is off by default, and the settings version bump
means it starts off after this update), the page loads, a log downloads, and
the clock sets from the browser.

Fixed in the same session, both found by using it:

- **The access point could not explain itself.** Five conditions hold the radio
  down and none printed anything unless it was taking down an access point that
  had already come up. An access point that never appears looked exactly like a
  firmware without the feature. `announce()` now prints a `service` line with
  the current reason.
- **The settings page fought back.** The panel never repainted a value changed
  from the web, and the web form rebuilt itself after every edit, throwing away
  focus and scroll position.

**Also fixed in the tidy-up afterwards**

- **The `Bad frames` counter had never worked.** `EngineDataModel::noteBadFrames`
  was added with its field and its reader in `4c0b53b`, but the call site was
  never written, so nothing ever put the adapter's splice and reject counts into
  the model. The DIAG page and the service page both showed `0`, in green,
  whatever the link was actually doing. Worth knowing when reading the results
  below: every `Bad frames: 0` recorded before 16 September 2026 means nothing.

**Still to check on the car**

- **A multi-file `.tar`.** The ustar headers are written by hand and the
  `Content-Length` is computed in a separate pass from the one that writes the
  bytes; if those two disagree by one byte the browser truncates or hangs.
  Select two or three, download, extract, and open **each** in the Client.
- **Selecting every file when there are many.** The names go to `/all.tar` in
  the query string. Thirty files is about a kilobyte of URL, and where the
  request line stops being accepted has not been established.
- **Deleting.** Never once run. Check that a throwaway file goes, that the list
  refreshes, and that the file currently being written cannot be selected.
- **Starting the engine mid-download.** The case the whole design leans on: the
  access point should drop, logging resume, and `framesDropped()` stay at zero.
  Read the count from the console afterwards rather than assuming. The DIAG
  page's `Bad frames` is now worth reading too - it counted nothing until this
  session.
- **The idle timeout.** Fifteen minutes with nobody connected should take the
  radio down, and it should stay down until the engine runs again. This is the
  guard standing between the feature and a flat battery overnight, and it is
  entirely unverified.
- **The voltage floor.** Below 12.0 V the access point should refuse to come up
  and say so on the console.
- **Rotation on engine stop.** The file for the drive just finished should be
  complete and open in the Client, and a new one should start.
- **The session name.** Set one, confirm the next file carries it, and that
  something like `run 3/4` comes out as `run-3-4`.
- **Turning logging off and back on** without a reboot. Off should close the
  file properly - the last few seconds live in a RAM buffer - and on should
  open a new one.
- **Settings and clock across a power cycle.** The flash write is debounced four
  seconds after the last edit; the clock has to be held by the RTC.
- **The SERVICE AP block on DIAG fits.** Its position was worked out by
  arithmetic against the column height, not by looking at it. Confirm the key
  row is not clipped at the bottom, and that the network name turns green and
  gains a count when a laptop joins.

---

## 2026-09-16 — IDLE and BOOST pages, not yet on the car

Both environments build and link. Nothing below has been observed on hardware;
this entry exists so the list is written down before the next trip to the car
rather than reconstructed at it.

**To check on the car**

- **`idleAngleCorr` goes negative and reads correctly.** The whole reason the
  decoder fix was made. Unlike `IgnAngle`, this one *is* testable on this car:
  the idle loop trims timing to hold its target, so the IDLE page's `IDLE IGN`
  tile should sit somewhere around zero and move in both directions at a
  steady idle. A reading pinned near +125 means the fix did not take.
- **The idle target mark lands where the Client says it does.** Compare the
  bar's mark against Idle Target in EMU Classic Client on the laptop.
- **`IDLE CTL` follows the loop.** Should read `CLOSED` at idle and `OPEN` off
  throttle above idle, matching the Client's Idle Control Active.
- **The boost table set number matches the Client's.** It is shown raw, on the
  assumption the ECU numbers its sets the same way its own software displays
  them. That assumption is untested and this is the one item most likely to be
  wrong.
- **Both correction terms show a sign and change it.** `IDLE PID` and
  `BOOST PID` are signed; a reading that never goes below zero is suspect.
- **Eight page dots still clear the page name.** The dot pitch was tightened
  from 10 px to 8 px for this. Read on the panel, not in a screenshot.
- **The display is the right way up, and touch agrees with it.** The panel is
  now rotated 180 degrees so the USB socket faces the reachable side. The
  image is the easy half to confirm; the half worth actually testing is touch,
  because a transform that did not turn with the image would still register
  presses - just mirrored. Swipe the pages left and right, and press a Setup
  button near an edge rather than in the middle, where a mirrored hit and the
  intended one land in the same place.
- **The pages exist and are reachable** without the object pool running out -
  see the standing worry in [decision-log.md](decision-log.md).

**Cannot be tested on this car**

- **The classic-protocol `n/a` state.** The car runs the EDL-1 build, so the
  path where `controlChannels` is false is only exercised by flashing
  `crowpanel_advance_35`, which nothing else needs.

---

## 2026-09-10 — .emulog logging opens in EMU Classic Client

Environment `crowpanel_advance_35_edl`, first run of the rewritten `EmuLog`.

**Confirmed on the car**

- Logs written by the dashboard **open in EMU Classic Client and read the same
  as ones the Client recorded itself**. Reported as working exactly as it
  should.

That closes the format question outright. It also confirms, indirectly, three
things that had no test of their own: the ROM miniz compressor works on this
chip, the SD write path holds up across a whole session, and the RTC is
reachable from `AppController` after being moved out of `DashUi` — a log gets
its name from the clock, so a file that opened at all had a name to open under.

**Also confirmed the same day**

Four things that had been carried as untested since the first run on 8
September, all reported working:

- **Settings survive a power cycle.** The stale NVS record that blocked this
  test earlier has been overwritten, so it could finally be checked at all.
- **Backlight PWM, brightness and night mode.**
- **The Setup page's Limits category.** This is the screen that builds the
  most LVGL objects of any page, and it was the standing worry about object
  pool headroom. It behaves.
- **The check-engine bit numbering.** Confirmed by the intended test -
  unplugging the intake air sensor and watching which flag lights. The
  numbering was an inference until now; it is right.

**Cannot be tested on this car**

- **`IgnAngle` going negative.** One of the 22 decoder fixes, and the only one
  that reaches the screen. The ECU has to pull timing below zero to exercise
  it - knock retard, launch control, ALS - and this setup does not do that.
  The fix stands on Ecumaster's own format definition, which declares the
  channel `sbyte`, rather than on a measurement. Recorded so it stops
  appearing on test lists.

**Not yet exercised**

The four UI changes made after this build was flashed - the AFR tile, alarm
list scrolling, the black palette and the two alarms defaulting off - plus
what the open items in the decision log still list.

---

## 2026-09-09 — clock, alarm list and SD logging on the car

Firmware: `0e2ef5c`, environment `crowpanel_advance_35_edl`. First run of the
RTC, the Alarms page and SD logging on the hardware.

**Confirmed with the ECU connected**

- Values read correctly on screen and behave sensibly on all six pages.
- **The alarm list works on EDL-1.** Events land in the order they happened,
  with times, and the page reads the way it was designed to.
- This covers three of the items the 8 September entry listed as untested:
  alarm behaviour on a real engine, the run summary, and SD logging.

**The RTC seeding rule was wrong the first time**

The panel came up reading 00:24 while the firmware reading it had been compiled
at 19:44, so no seed had been written. The condition was the chip's VL flag
alone, and VL only says the oscillator stopped — it says nothing about whether
the time is right. With the backup cell fitted since the factory the clock had
been running the whole time and had never been set, VL clear throughout.

Fixed by adding a plausibility test: a clock reading earlier than the build it
is being read by has never been set. Verified on the next boot — the clock came
up correct and, on subsequent boots, was left alone rather than reseeded.

**SD logging: works, but mounted intermittently and the cause is unknown**

- With no card, `sdCommand(): Card Failed! cmd: 0x00` at CMD0, as expected.
- With a card, the same build over four consecutive resets: mount, fail,
  mount, fail. Card, wiring and filesystem are constant across those four, so
  none of them is the variable.
- Lowering the SPI clock from 80 MHz to 25 MHz **did not change it**. That was
  still worth doing — 80 MHz is outside what SD in SPI mode supports — but it
  was a fix for a different problem.
- A later session of eleven consecutive resets all mounted, every one on the
  **first** attempt, so the retry added in between never ran and cannot be
  credited. Something outside the firmware changed; card seating is the guess.
  Recorded as an open item rather than a closed one.

The file-number sequence is what proves the eleven: visible banners showed
00009, 00010, 00014, 00015, 00016 and 00019, and the gaps line up exactly with
the boots whose banner was lost, so those mounted too.

**Two smaller findings**

- **The console showed nothing after an upload.** All boot output is printed
  inside the first second, and a monitor attached afterwards misses it. The
  announce-on-connect added for this was not enough on its own: `Serial` reads
  as connected on this USB-CDC port before the host has re-opened it, so on
  about half the resets the reprint also went nowhere. Pressing any key now
  reprints the state, which does not depend on winning a race.
- **Stored settings were discarded.** `getBytes(): not enough space in buffer:
  132 < 136` — the record in NVS was written by a firmware whose `DashSettings`
  was four bytes larger. The size and version check rejected it and fell back
  to defaults, which is the designed behaviour. It stops once any setting is
  saved.

**Still untested**

- Whether the bad-frame count stays at zero while the card is being written —
  a long write during logging is the case that would push it.
- Whether the SD mount survives vibration in the car.
- Whether settings survive a power cycle (the stale record above has to be
  overwritten once before this can be checked at all).
- Backlight PWM, brightness and night mode.
- Whether the log file opens in EMU Classic Client. It does not, and the
  format question is still open.

---

## 2026-09-08 — EDL-1 link, after the framing fix

Firmware: `4c0b53b`, environment `crowpanel_advance_35_edl`. ECU reconfigured
to stream the EDL-1 logger protocol.

**Confirmed**

- The EDL-1 stream decodes correctly. Values read right on screen.
- **Bad frames stays at zero.** The 2048-byte receive buffer, the next-marker
  check and the plausibility gate together hold the link clean under normal
  running.
- Communication described as faultless over the session.

**What this replaces**

The first EDL-1 attempt showed bursts of impossible values across several
fields at once — CLT max 27472 C, oil pressure 15.9 bar, invented CEL flags.
Root cause was the 256-byte default UART buffer being smaller than one
260-byte frame. See the decision log.

**Still untested on EDL-1**

- Alarm behaviour across a real start, hysteresis, latching, run summary.
- Settings surviving a power cycle.
- Anything to do with SD logging.
- Whether the bad-frame count stays at zero under load — a long card write or
  a settings save is the case that would push it.

---

## 2026-09-08 — first run connected to the ECU

Firmware: `2bcd7a8` (five pages, settings in flash) on the CrowPanel Advance
3.5, ECU link through the MAX3232 on the EMU Classic extension port.

**Confirmed**

- Flashing over USB-C succeeds.
- The serial link comes up with the ECU connected.
- The user interface behaves logically — pages and navigation do what they
  are supposed to.
- Displayed values look correct as far as they have been checked against the
  ECU.

**Not tested yet**

- SD card logging. It is on the `feature/sd-logging` branch, which was not
  flashed.
- Alarm behaviour with a real engine running: the arming delay across a
  start, hysteresis on a value sitting at its limit, latching, and the
  engine-off run summary. All of it is untested against a real start.
- The Setup page under load: whether the LVGL object pool holds the Limits
  category, and whether vertical scrolling fights the horizontal page swipe.
- Backlight PWM, brightness and night mode.
- Whether settings actually survive a power cycle.

**Nothing to fix from this run.** No defects were observed.

### Worth checking on the next run

The two things most likely to be wrong are both alarm-related, because they
have never seen a real engine: whether the arming delay is long enough for oil
pressure to build on this engine, and whether the invented thresholds are
anywhere near right. Both are adjustable on the Setup page now, so the next
drive is the place to find out rather than a reflash.

---

## 2026-09-08 (later) — findings from the first run

Observed on the car and fixed in the same session:

- **The engine-off summary never appeared.** Cutting the ignition kills the ECU
  before RPM falls, so the last frame freezes at a few hundred rpm and the
  summary's trigger never fired. It now also ends the run on link loss, and is
  checked every pass rather than only when a frame arrives.
- **The idle return to Drive was unwanted.** It moved the screen away while a
  page was still being read. Removed; pages change only by swipe.
- **Three seconds of arming delay was too short.** Raised to six.
- **The boot sweep was over before you could look at it.** 900 ms to 2600 ms.
- **Cells looked washed out.** Panels darkened and the dividing lines lifted, so
  the numerals read against near-black.

Defaults corrected from what the car actually does: fuel pressure warn 3.2 to
2.2 bar and critical 2.6 to 1.9 bar, shift first light 3 500 to 1 000 rpm, red
zone 6 800 to 6 000.

Note that the settings blob version was bumped, so **the first boot after this
update discards any settings stored on the device** and comes up on the new
defaults.

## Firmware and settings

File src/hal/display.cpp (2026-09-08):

#include "display.hpp"

#include <Arduino.h>
#include <LovyanGFX.hpp>
#include <driver/i2c.h>
#include <esp_heap_caps.h>
#include <lvgl.h>

#include "board_config.hpp"

namespace display {
namespace {

// Panel wiring, transcribed from Elecrow's LovyanGFX_Driver.h for this board.
// See board_config.hpp for the source links.
class CrowPanelLgfx : public lgfx::LGFX_Device {
public:
    CrowPanelLgfx() {
        {
            auto cfg = bus_.config();
            cfg.spi_host = SPI2_HOST;
            cfg.spi_mode = 0;
            cfg.freq_write = board::kLcdSpiWriteHz;
            cfg.freq_read = board::kLcdSpiReadHz;
            cfg.spi_3wire = false;
            cfg.use_lock = true;
            cfg.dma_channel = SPI_DMA_CH_AUTO;
            cfg.pin_sclk = board::kLcdSclkPin;
            cfg.pin_mosi = board::kLcdMosiPin;
            cfg.pin_miso = board::kLcdMisoPin;
            cfg.pin_dc = board::kLcdDcPin;
            bus_.config(cfg);
            panel_.setBus(&bus_);
        }
        {
            auto cfg = panel_.config();
            cfg.pin_cs = board::kLcdCsPin;
            cfg.pin_rst = board::kLcdRstPin;
            cfg.pin_busy = -1;
            cfg.memory_width = board::kPanelWidth;
            cfg.memory_height = board::kPanelHeight;
            cfg.panel_width = board::kPanelWidth;
            cfg.panel_height = board::kPanelHeight;
            cfg.offset_x = 0;
            cfg.offset_y = 0;
            cfg.offset_rotation = board::kPanelRotation;
            cfg.dummy_read_pixel = 8;
            cfg.dummy_read_bits = 1;
            cfg.readable = false;
            cfg.invert = true;
            cfg.rgb_order = false;
            cfg.dlen_16bit = false;
            cfg.bus_shared = true;
            panel_.config(cfg);
        }
        {
            auto cfg = touch_.config();
            cfg.x_min = 0;
            cfg.x_max = board::kPanelWidth - 1;
            cfg.y_min = 0;
            cfg.y_max = board::kPanelHeight - 1;
            cfg.pin_int = board::kTouchIntPin;
            cfg.pin_rst = board::kTouchRstPin;
            cfg.bus_shared = false;
            cfg.offset_rotation = 0;
            cfg.i2c_port = I2C_NUM_0;
            cfg.pin_sda = board::kTouchSdaPin;
            cfg.pin_scl = board::kTouchSclPin;
            cfg.freq = board::kTouchI2cHz;
            cfg.i2c_addr = board::kTouchI2cAddr;
            touch_.config(cfg);
            panel_.setTouch(&touch_);
        }
        setPanel(&panel_);
    }

private:
    lgfx::Panel_ILI9488 panel_;
    lgfx::Bus_SPI bus_;
    lgfx::Touch_GT911 touch_;
};

CrowPanelLgfx gfx;

// Two partial buffers in internal DMA-capable RAM. Full-screen buffers would
// have to live in PSRAM, which flushes noticeably slower.
// Backlight PWM. 5 kHz is well above anything the eye or a phone camera picks
// up, and 8 bits is finer than the panel's usable range anyway.
constexpr uint8_t kBacklightChannel = 0;
constexpr uint32_t kBacklightFreqHz = 5000;
constexpr uint8_t kBacklightBits = 8;

constexpr uint32_t kBufferLines = 40;
constexpr uint32_t kBufferPixels = board::kLcdWidth * kBufferLines;

lv_disp_draw_buf_t drawBuf;
lv_color_t* buf0 = nullptr;
lv_color_t* buf1 = nullptr;

void flushCb(lv_disp_drv_t* drv, const lv_area_t* area, lv_color_t* pixels) {
    if (gfx.getStartCount() > 0) {
        gfx.endWrite();
    }
    gfx.pushImageDMA(area->x1,
                     area->y1,
                     area->x2 - area->x1 + 1,
                     area->y2 - area->y1 + 1,
                     reinterpret_cast<lgfx::rgb565_t*>(pixels));
    lv_disp_flush_ready(drv);
}

void touchCb(lv_indev_drv_t* drv, lv_indev_data_t* data) {
    uint16_t x = 0;
    uint16_t y = 0;

    if (gfx.getTouch(&x, &y)) {
        data->state = LV_INDEV_STATE_PR;
        data->point.x = x;
        data->point.y = y;
    } else {
        data->state = LV_INDEV_STATE_REL;
    }
}

}  // namespace

bool begin() {
    gfx.init();
    gfx.initDMA();
    gfx.startWrite();
    gfx.fillScreen(TFT_BLACK);

    // Backlight on only after the panel is cleared, to avoid a flash of noise.
    ledcSetup(kBacklightChannel, kBacklightFreqHz, kBacklightBits);
    ledcAttachPin(board::kLcdBacklightPin, kBacklightChannel);
    setBrightness(100);

    lv_init();

    const size_t bytes = kBufferPixels * sizeof(lv_color_t);
    buf0 = static_cast<lv_color_t*>(heap_caps_malloc(bytes, MALLOC_CAP_DMA | MALLOC_CAP_INTERNAL));
    buf1 = static_cast<lv_color_t*>(heap_caps_malloc(bytes, MALLOC_CAP_DMA | MALLOC_CAP_INTERNAL));
    if (buf0 == nullptr || buf1 == nullptr) {
        return false;
    }

    lv_disp_draw_buf_init(&drawBuf, buf0, buf1, kBufferPixels);

    static lv_disp_drv_t dispDrv;
    lv_disp_drv_init(&dispDrv);
    dispDrv.hor_res = board::kLcdWidth;
    dispDrv.ver_res = board::kLcdHeight;
    dispDrv.flush_cb = flushCb;
    dispDrv.draw_buf = &drawBuf;
    lv_disp_drv_register(&dispDrv);

    static lv_indev_drv_t indevDrv;
    lv_indev_drv_init(&indevDrv);
    indevDrv.type = LV_INDEV_TYPE_POINTER;
    indevDrv.read_cb = touchCb;
    lv_indev_drv_register(&indevDrv);

    return true;
}

void loop() {
    lv_timer_handler();
}

void setBrightness(uint8_t percent) {
    if (percent > 100) {
        percent = 100;
    }
    const uint32_t duty = (static_cast<uint32_t>(percent) * 255u) / 100u;
    ledcWrite(kBacklightChannel, duty);
}

}  // namespace display

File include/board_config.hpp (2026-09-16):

#pragma once

#include <stdint.h>

// Board / wiring constants for the Elecrow CrowPanel Advance 3.5" HMI
// (ESP32-S3-WROOM-1-N16R8).
//
// Sources - do not guess these, they are taken from Elecrow's own material:
//   Wiki:  https://www.elecrow.com/wiki/CrowPanel_Advance_3.5-HMI_ESP32_AI_Display.html
//   Demos: github.com/Elecrow-RD/CrowPanel-Advance-3.5-HMI-ESP32-S3-AI-Powered-
//          IPS-Touch-Screen-480x320  (example/V1.0/Arduino/lesson-03 and -05)
//
// Everything that depends on the physical board lives here so the layers
// above stay board agnostic.
namespace board {

// ---------------------------------------------------------------- ECU link --
// The EMU's EDL-1 logger stream: 260-byte frames at 115200 baud, 8N1. The ECU
// has to be configured to send it - see ecu_link.hpp.
constexpr uint32_t kEcuBaudEdl = 115200;

// UART1-OUT connector on the CrowPanel, fed from the MAX3232 RS232-TTL
// adapter. NOTE: GPIO16 (used on the previous esp32dev bring-up board) is the
// GT911 touch I2C clock here and must not be reused for the ECU.
constexpr int8_t kEcuRxPin = 18;  // UART1-OUT RX

// TX is attached because that is the wiring the link was verified with.
//
// It is never used: nothing in this project writes to the ECU port, and the
// EMU's extension port is a one-way stream in the first place (see the BT
// Module manual, "Data transmission: One-way"). Keeping the pin assigned
// matches the tested configuration rather than changing two things at once.
constexpr int8_t kEcuTxPin = 17;  // UART1-OUT TX - assigned, never driven

// ----------------------------------------------------------------- Console --
// USB CDC. Matches monitor_speed in platformio.ini.
constexpr uint32_t kDebugBaud = 115200;

// ----------------------------------------------------------------- Display --
// ILI9488 on SPI2_HOST. The panel itself is 320x480 portrait; an odd
// offset_rotation presents it as 480x320 landscape.
constexpr uint16_t kLcdWidth = 480;
constexpr uint16_t kLcdHeight = 320;
constexpr uint16_t kPanelWidth = 320;
constexpr uint16_t kPanelHeight = 480;

// 1 rather than 3: the same landscape, turned 180 degrees, which puts the USB
// socket on the reachable side once the dash is mounted in the car. Nothing
// else has to change for it - LovyanGFX folds this into the rotation it
// converts raw touch coordinates with, so the touch panel turns with the
// image rather than needing its own correction.
constexpr uint8_t kPanelRotation = 1;

constexpr int8_t kLcdSclkPin = 42;
constexpr int8_t kLcdMosiPin = 39;
constexpr int8_t kLcdMisoPin = -1;
constexpr int8_t kLcdDcPin = 41;
constexpr int8_t kLcdCsPin = 40;
constexpr int8_t kLcdRstPin = 2;
constexpr int8_t kLcdBacklightPin = 38;

constexpr uint32_t kLcdSpiWriteHz = 40000000;
constexpr uint32_t kLcdSpiReadHz = 16000000;

// --------------------------------------------------------------- SD card --
// microSD slot on its own SPI bus (HSPI), separate from the display's SPI2.
//
// Verified against Elecrow's schematic for board v1.4 (Eagle_SCH&PCB/1.4):
// nets IO4_SD_MISO, IO5_SD_SCK, IO6_SD_MOSI and IO7_SD_CS all run from the
// ESP32 to the holder J5. An earlier comment here claimed the chip select was
// not routed and that pin 7 was a placeholder; that was wrong, J5.CS is on
// IO7.
constexpr int8_t kSdMosiPin = 6;
constexpr int8_t kSdMisoPin = 4;
constexpr int8_t kSdSckPin = 5;
constexpr int8_t kSdCsPin = 7;

// SD in SPI mode does not go anywhere near 80 MHz - the bus tops out around
// 25 MHz in practice, and the previous value was simply out of spec. Card
// initialisation runs at 400 kHz regardless, so this governs the transfers
// after mounting.
constexpr uint32_t kSdSpiHz = 25000000;

// ------------------------------------------------------------------- Touch --
// GT911 capacitive controller. Shares I2C0 with the on-board RTC.
constexpr int8_t kTouchSdaPin = 15;
constexpr int8_t kTouchSclPin = 16;
constexpr int8_t kTouchIntPin = 47;
constexpr int8_t kTouchRstPin = 48;
constexpr uint8_t kTouchI2cAddr = 0x14;  // alternative: 0x5D
constexpr uint32_t kTouchI2cHz = 400000;

}  // namespace board

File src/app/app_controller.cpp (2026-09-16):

#include "app_controller.hpp"

#include <lvgl.h>

#include "alarm_engine.hpp"
#include "board_config.hpp"
#include "date_time.hpp"
#include "display.hpp"
#include "ecu_link.hpp"
#include "rtc_clock.hpp"

namespace ecu {
namespace {

void settingsChangedCb(void* context) {
    static_cast<AppController*>(context)->settingsChanged();
}

}  // namespace

AppController::AppController()
    : ecuUart_(1),  // UART1
      model_(),
      provider_(ecuUart_, model_),
      report_(Serial) {}

void AppController::begin() {
    Serial.begin(board::kDebugBaud);

    provider_.begin();

    if (!store_.load(settings_)) {
        Serial.println(F("settings: no stored record, using defaults"));
    }

    // Before the display: the log is named after the date, and a dashboard
    // whose screen failed should still record the drive.
    rtc_.begin();
    openLogWhenNamed();
    serviceAp_.begin(settings_);

    displayReady_ = display::begin();
    if (displayReady_) {
        ui_.begin(lv_scr_act(), rtc_, settings_, settingsChangedCb, this);
    } else {
        Serial.println(F("display: LVGL buffer allocation failed, running headless"));
    }

    ServiceContext service;
    service.log = &provider_.log();
    service.model = &model_;
    service.rtc = &rtc_;
    service.ap = &serviceAp_;
    service.alarms = displayReady_ ? &ui_.alarms() : nullptr;
    service.settings = &settings_;
    service.onSettingsChanged = settingsChangedCb;
    service.pump = pumpDisplay;
    service.context = this;
    servicePage_.begin(service);

    Serial.println();
    Serial.println(F("ECU dashboard - EMU Classic serial link (read-only)"));
}

// Sending a few megabytes off the card is seconds of work. Without this the
// screen would be frozen for all of it, which on a dashboard reads as a crash.
void AppController::pumpDisplay(void* context) {
    AppController* self = static_cast<AppController*>(context);
    if (self->displayReady_) {
        display::loop();
    }
}

// Everything this firmware has to say about its own state is printed inside
// the first second after reset - long before a monitor opened after the upload
// has attached to the port, so the console shows an empty screen and no way to
// tell whether the board is alive. Waiting for the host at boot would be worse:
// in the car nobody is listening and the dashboard would just come up later.
//
// So say it again once loop() starts. That is not enough on its own: `Serial`
// reads as connected on this USB-CDC port well before the host has actually
// re-opened it after a reset, so on roughly half the resets this print still
// goes nowhere. Hence the second trigger in loop() - press any key and the
// board says where it stands, whenever you ask.
void AppController::announce() {
    Serial.println();
    Serial.println(F("---------------- DASH ----------------"));

    Serial.print(F("build     : "));
    Serial.print(F(__DATE__));
    Serial.print(' ');
    Serial.println(F(__TIME__));

    Serial.print(F("ECU link  : "));
    Serial.print(kEcuLinkName);
    Serial.print(F(" @ "));
    Serial.print(kEcuLinkBaud);
    Serial.print(F(" baud, "));
    Serial.println(toString(model_.linkState(millis())));

    Serial.print(F("clock     : "));
    if (rtc_.present()) {
        char stamp[9];
        formatHms(rtc_.now(), stamp, sizeof(stamp));
        Serial.println(stamp);
    } else {
        Serial.println(F("not available"));
    }

    Serial.print(F("log       : "));
    if (provider_.log().ready()) {
        Serial.print(provider_.log().fileName());
        Serial.print(F("  frames="));
        Serial.print(provider_.log().framesWritten());
        Serial.print(F("  bytes="));
        Serial.print(provider_.log().bytesWritten());
        if (provider_.log().framesDropped() > 0) {
            Serial.print(F("  dropped="));
            Serial.print(provider_.log().framesDropped());
        }
        Serial.println();
    } else {
        Serial.print(F("off - "));
        Serial.println(provider_.log().failure());
    }

    // Says the feature is in this build even when the radio is down, and names
    // the one condition holding it down. Five of them can, and none is visible
    // from outside the car.
    Serial.print(F("service   : "));
    if (serviceAp_.serving()) {
        Serial.print(serviceAp_.ssid());
        Serial.print(F(" at http://"));
        Serial.print(serviceAp_.ipAddress());
        Serial.print(F("  clients="));
        Serial.println(serviceAp_.clients());
    } else {
        Serial.print(F("down - "));
        Serial.print(serviceAp_.reason());
        const uint32_t left = serviceAp_.armingSecondsLeft(millis());
        if (left > 0) {
            Serial.print(F(" ("));
            Serial.print(left);
            Serial.print(F(" s to go)"));
        }
        Serial.println();
    }

    Serial.print(F("display   : "));
    if (displayReady_) {
        Serial.println(F("up"));
    } else {
        Serial.println(F("failed, running headless"));
    }
    Serial.println();
}

// The log file is named after the date and nothing else in the format carries
// it, so there is no log until the clock can name one. Retried every pass
// because the RTC is on the touch I2C bus and may answer late.
void AppController::openLogWhenNamed() {
    if (logOpened_) {
        return;
    }
    if (!settings_.logging) {
        // Said once, not every pass: the reason has to survive to the console
        // and to the service page, but it is not news on the second loop.
        logOpened_ = true;
        provider_.log().disable("turned off in setup");
        return;
    }
    if (rtc_.now().valid) {
        logOpened_ = true;
        provider_.log().begin(rtc_.now());
        return;
    }
    if (!rtc_.present()) {
        // No clock at all. Naming the log after the build gives a wrong date
        // on a readable file, which beats not recording the drive. The
        // collision suffix in EmuLog keeps a second run from erasing the
        // first, since every run would otherwise pick the same name.
        logOpened_ = true;
        Serial.println(F("emulog: no RTC, naming the log after the build"));
        provider_.log().begin(buildTime());
    }
}
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

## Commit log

2026-09-06 Add layered ECU data path between EMUSerial and the app
    Fills in the protocol / model / provider split the architecture calls for,
    so main.cpp is no longer the whole application.
    EmuSerialAdapter is now the only place that includes EMUSerial.h. It wraps
    the GTO2013 reference decoder unchanged - no protocol details are reinvented
    and no scaling is derived locally - and translates emu_data_t into the
    model's own snapshot type.
    EngineDataModel holds that snapshot in engineering units together with link
    health (Online / Stale / Offline derived from frame arrival timing) and a
    revision counter that only advances on a real value change, so the UI can
    skip redraws cheaply. It has no knowledge of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
    [app_controller.cpp, board_config.hpp, ecu_data_provider.cpp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]
2026-09-06 Target the CrowPanel Advance 3.5 and bring up the LVGL dashboard
    Replaces the esp32dev bring-up environment with the real target: an
    ESP32-S3-WROOM-1-N16R8 with 16 MB QIO flash, 8 MB octal PSRAM, an ILI9488
    480x320 IPS panel and a GT911 touch controller.
    The pin move matters beyond the board name. GPIO16, used for the ECU RX
    line during bring-up, is the GT911 touch I2C clock on this board, so the
    ECU link moves to the UART1-OUT connector on GPIO18. TX stays unassigned.
    Every pin in board_config.hpp is transcribed from Elecrow's wiki and demo
    sources, cited in the header rather than guessed.
    display.cpp keeps LovyanGFX and the panel wiring behind a two-function
    interface, so the screens onl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
    [app_controller.cpp, board_config.hpp, display.cpp]
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2026-09-06 Document the ECU extension port and the enclosure
    The dashboard replaces the Ecumaster BT Module on the EMU Classic's extension
    port, which settles where it plugs in and where the MAX3232 is powered from:
    the ECU, at 3.3 V. The BT Module manual is quoted for the rule that matters —
    the port also carries a +5 V pin that "must not be used", and 5 V "may result
    in permanent damage".
    Two consequences are called out because both are easy to get wrong: leave the
    +5 V pin unconnected, and do not bridge the ECU's 3.3 V to the panel's own
    rail. Only the grounds are common, and they must be.
    The manual gives its pin numbering in a figure rather than as text, so those
    numbers are recorded as an ope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
    [case.scad]
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2026-09-06 Quieten alarms, sweep the lights at power-up
    Four changes to how the dash behaves, all from watching the mockup.
    Alarms no longer move the page. Colouring the cell and naming the alarm in the
    status bar - which is on screen whichever page is up - already tells the
    driver everything the page pull did, without taking away whatever they had
    deliberately chosen to look at. The rule table loses its page column and the
    engine loses the request mechanism entirely.
    Power-up opens Drive and sweeps the shift lights: fill, hold red, clear. It
    replaces a self-test screen that was neither attractive nor much use, and it
    is the one moment the driver can confirm every segment works. The sweep is
    non-bloc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
    [dash_page.hpp]
2026-09-08 Arm alarms on a delay, hold them through a threshold, latch what tripped
    Fixes the bug that would have shown up on the first drive: the 500 rpm gate
    opened the instant the engine caught, while oil pressure was still building
    and the battery was still down from the starter. Both are critical by any
    sensible limit, so every single start fired two red alarms - the fastest way
    to teach a driver that red means nothing. The engine now has to have been
    running for the arming delay, three seconds by default, and the status bar
    says so rather than going quiet.
    Thresholds gain a deadband. A value sitting on its limit used to flicker its
    cell at the frame rate; an alarm now trips at the limit and clea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
2026-09-08 Add the setup page and store settings in flash
    The thresholds the dash has been running on were all invented - 1.0 bar,
    108 C, 0.95 lambda, a 6 800 rpm red zone - and none was measured against this
    engine. They are now editable on the car, on a fifth page, and kept in NVS as
    one versioned blob.
    Only numbers and on/off flags are exposed. Which value an alarm watches and
    which way it trips stays in the rule table: a settings page that can rewire
    logic is one that can brick the dash on a dark road.
    The page stays usable with the engine running. Locking it while stopped was
    the first design and it was wrong - setting an oil pressure limit without
    watching the live value it guards is the guessw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
    [display.cpp]
2026-09-08 Update the documentation to match what now runs on the car
    The README no longer claims the firmware has never been driven: it was
    flashed and run connected to the ECU on 8 September, and docs/test-results.md
    records what that run actually confirmed and the much longer list it did not.
    The architecture diagram gains the settings layer, the alarm section gains
    arming, hysteresis and latching, and the page count is five. The pin table
    says the backlight is PWM rather than a level.
    The decision log's open items are rewritten: running on the car is no longer
    one of them, and three real ones replace it - untested SD logging, the UI
    repainting at frame rate, and the unmeasured LVGL object pool.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
2026-09-08 Fix what the first drive found
    A run now ends when the data stops, not when the revs do. Cutting the ignition
    kills the ECU as well, so the last frame it sends freezes at a few hundred rpm
    and the model keeps reporting it - the summary's trigger was waiting for a
    number that would never fall. It now also closes the run on link loss, and is
    checked on every pass rather than only when a frame arrives, which is the half
    that actually mattered: the situation it exists for is the one where frames
    have stopped.
    The idle return to Drive is gone. It moved the screen out from under the driver
    while they were still reading a page they had deliberately opened. Nothing but
    a swipe changes the page now.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
2026-09-08 Add an EDL-1 adapter beside the classic one
    The EMU can stream its EDL-1 logger protocol instead of the classic serial
    one: 195 channels in a 260-byte frame at 115200, against 34 channels sent one
    per 5-byte frame at 19200. Every value in a frame comes from the same instant,
    which is both what a dashboard wants and the shape a log file needs.
    ThiloZ/EDLSerial (MIT) is vendored unmodified and does the field extraction.
    Framing is done in the adapter instead, because the library's own resync is
    wrong: it collects 260 bytes, checks the marker, and on a mismatch discards the
    whole buffer - which preserves the phase error, so a listener that starts
    mid-frame stays misaligned indefinitely, and ev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
    [board_config.hpp, ecu_data_provider.cpp]
2026-09-08 Stop dropped bytes from reaching the screen as impossible values
    Reported from the car: brief bursts where several fields go wrong at once -
    CLT max 27472 C, oil pressure 15.9 bar, nonsense check-engine flags. Several
    fields wrong simultaneously is the signature of a misaligned frame, not a bad
    sensor, and it pointed straight at the framing.
    The root cause is that Arduino's default UART receive buffer is 256 bytes,
    smaller than one 260-byte EDL frame and only about 22 ms of slack at 115200.
    Any redraw, card write or settings save that holds the loop longer drops
    bytes, and a dropped byte splices two frames into one that still starts with a
    valid marker. The buffer is now 2048 bytes, which i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
    [ecu_data_provider.cpp]
2026-09-08 Adopt EDL-1 as the protocol the car runs
    The branch existed to keep an unproven protocol out of main. It is proven now:
    tested on the car, values correct, and the bad-frame counter sitting at zero.
    Both adapters stay in the tree behind one interface. The default build becomes
    EDL-1, because that is how the ECU is configured and building classic against
    an EDL-1 ECU gives a dashboard that shows nothing - a trap worth removing from
    the default.
    Documentation follows the move: the README gains a comparison of the two
    protocols and how to build either, the architecture diagram gains the second
    adapter and what earns its confidence without a checksum, and the decision log
    records both why EDL-1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
2026-09-09 Set the RTC when its time is implausible, not only when it stopped
    VL says the oscillator stopped. It does not say the time is right, and I
    wrote the seed as though it did.
    A BM8563 kept alive by its backup cell since the factory has a clock that
    has been running the whole time and has never been set: VL is clear and
    the registers hold a number that means nothing. begin() then refused to
    touch it, which is precisely backwards. On this board the panel came up
    reading 00:24 while the firmware reading it had been compiled at 19:44.
    Second trigger: a clock cannot legitimately read earlier than the moment
    the firmware reading it was compiled. Anything that does has never been
    set. Once seeded t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
    [rtc_clock.cpp]
2026-09-09 Print the startup state again when the console attaches
    Everything this firmware has to say about itself is printed inside the
    first second after reset. A monitor opened after the upload attaches
    seconds later, so the console shows an empty screen and no way to tell
    whether the board is alive - which is exactly what it looked like from
    the outside.
    Waiting for the host at boot would fix the console and break the car:
    nobody is listening there and the dashboard would simply come up later.
    So the state is printed once more at the moment the port is actually
    opened, which costs nothing when nobody ever opens it.
    Reports the build timestamp too. With the clock seeded from __TIME__ that
    is not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
    [app_controller.cpp]
2026-09-09 Say why SD logging is off, and correct two wrong SD constants
    The banner reported "off, no card" for every failure, including the case
    where a card is present and something else went wrong - which is exactly
    the case on this board now. It reads EmuLog::ready() and had no way to
    know more, so EmuLog keeps the reason and the banner prints it.
    This matters because the boot messages cannot be caught: log_.begin()
    runs a few hundred ms after reset, well before a monitor attached after
    an upload has opened the port. The reason has to survive somewhere it can
    be asked for later.
    Two constants were wrong as well, both found by reading Elecrow's
    schematic for board v1.4 rather than by guessing: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
    [app_controller.cpp, board_config.hpp, emu_log.cpp]
2026-09-09 Retry the SD mount, and print the state on demand
    Measured on the board, same card, same build, four consecutive resets:
    mounted, failed, mounted, failed. Dropping the bus clock from 80 to
    25 MHz changed nothing, so that was a real fix for a different problem
    and not this one. It is not the card, not the filesystem and not the
    wiring - all three are constant across those four boots. It is
    initialisation timing, so begin() now gets three goes 100 ms apart and
    says which one worked.
    The console trigger needed fixing too, for the same reason this took so
    long to see. `Serial` reads as connected on this USB-CDC port before the
    host has actually re-opened it after a reset, so the announce on the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
    [app_controller.cpp, emu_log.cpp]
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2026-09-09 Fix 22 channels the EDL decoder read wrongly
    Cross-checked all 195 fields against docs/ecu-formats/version1_211.xml,
    Ecumaster's own format definition, whose storage attribute is authoritative
    for width and signedness.
    Nineteen signed channels were read unsigned, so any negative reading came out
    as a large positive one: a 0.5 degree ignition retard as +127.5. Three are
    provably wrong in real logs - wboIPMeas and wboIPNorm in 83% of samples,
    dwellError in 23%. IgnAngle is the one that reaches the screen; it is correct
    throughout both sample logs and wrong the moment the ECU pulls timing.
    Two are percent7, a 7-bit percentage where raw 0..127 spans 0..100%. They were
    passed through raw, overs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
2026-09-09 Document the real .emulog format, and replace the tool that assumed another
    The format doc described validated 5-byte classic frames concatenated into a
    .emualog file, learned from a third-party project and never verified. It was
    wrong in every particular.
    What EMU Classic Client actually writes is a gzip stream over a 12-byte header
    and 256-byte records, where a record is the 260-byte EDL-1 frame with its
    32 40 50 60 marker stripped. Established from Antti's own logs and CSV exports
    - record count matches row count exactly, 17 channels line up with the vendored
    decoder's field map at data[i+4] across 20387 samples, and the marker appears
    zero times in 5.2 MB of log - then proven by buildin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
2026-09-09 Show AFR instead of lambda on the Tune page
    Same measurement, the unit Antti reads mixture in. The deviation bar keeps its
    meaning: +/- 1.8 AFR is the same mixture error the +/- 0.12 lambda span was.
    The Lean alarm still watches lambda and still lights this tile, because it is
    the same quantity underneath.
    Also stop the bar pegging when there is no target. The ECU sends afrTarget as
    zero when none is configured - it did for an entire sample log - and measuring
    against zero held the bar hard over, which reads as a fault that is not there.
    No target now shows "tgt --" and a centred bar.
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2026-09-10 Close four open test items, and one that cannot be closed
    Confirmed on the car: settings survive a power cycle, backlight PWM and night
    mode work, the Setup page's Limits category behaves, and the check-engine bit
    numbering is right.
    The last two each retire a standing worry. Limits is the screen that builds
    the most LVGL objects, which was the whole basis for suspecting the object
    pool; it is still unmeasured but no longer suspect. The CEL numbering had been
    an inference since it was written, and the intended test - unplug the intake
    air sensor, see which flag lights - has now been run.
    IgnAngle going negative is recorded as untestable rather than untested. It
    needs the ECU to pull timing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
2026-09-16 Close the log when the engine stops, and make the logging switch work
    Three things the service page needs from the logger, and one that was
    simply broken.
    DashSettings::logging was set in the defaults and read by nothing:
    openLogWhenNamed() started the log unconditionally. It is honoured now,
    and can be turned off and on again without a reboot - off closes the
    file rather than abandoning it, because the last few seconds live in a
    RAM buffer until something flushes them.
    EmuLog::rotate() closes the current file and opens the next one without
    remounting the card or reallocating the compressor. The controller calls
    it when the engine stops, so the drive that just ended is a complete
    file that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
    [app_controller.cpp, emu_log.cpp]
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2026-09-16 Show the access point on the status bar, and write down why
    The status bar gains WIFI, and WIFI with a count once a laptop has
    joined, so the driver can tell whether the network is actually up
    without walking round to the laptop. Empty whenever the radio is off,
    which is whenever the car is moving.
    The decision log gets the two reversals this feature went through: the
    cloud upload that was designed in detail and then undone by the fact
    that the logs are read on the laptop that comes to the car anyway, and
    the deletion that was left out on an argument about disk space when the
    question had been about carrying the card indoors.
    [app_controller.cpp]
2026-09-16 Carry the idle and boost loop state in the snapshot
    Ten channels the EDL-1 stream already decodes but nothing read: where each
    loop is aiming, what it drives its valve to, and how much of that duty is the
    PID correcting.
    The classic 35-channel protocol has no idle or boost channel whatsoever, so
    the snapshot carries a controlChannels flag rather than letting the pages
    guess. A zero cannot be read as absence here - a closed idle valve and a
    missing channel both decode to 0 % - and the flag is set by the adapter rather
    than by an ifdef so the UI stays protocol-agnostic.
    boostTargetKpa is absolute kPa, the same scale mapKpa already uses, so target
    and actual can be drawn against one axis with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
    [engine_data.hpp]
2026-09-16 Add the IDLE page
    Seven values that answer one question in the pit: is the idle loop holding,
    and what is it doing to hold it. RPM against target on the hero row, the valve
    duty and the PID's share of it side by side underneath, then the timing the
    loop is asking for, with AFR and MAP as the context that explains both.
    The hero bar is absolute, 0..2000 rpm with the target as a mark, not the
    deviation bar TUNE uses for mixture. A deviation reads as a fault whenever the
    loop is open, and driving away would peg it for the rest of the session.
    The correction terms print their sign. Which way the loop is pushing is the
    reading; the magnitude alone says nothing.
    On the classic protocol the four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
2026-09-16 Add the BOOST page
    Built like IDLE, because it is the same question about a different loop: MAP
    against boostTarget on one absolute 0..220 kPa scale, then the solenoid duty
    with the PID correction and the error correction beside it - the two terms
    that say why the duty is where it is.
    Absolute kPa, not the gauge bar DRIVE shows. boostTarget is stated in absolute
    kPa by the ECU, and converting one of the pair to read against the other would
    put arithmetic between the driver and the comparison. 220 kPa full scale is
    about 1.2 bar of gauge boost, with atmospheric just under halfway, so off
    boost is a position rather than a number.
    The table set is shown as the ECU numbers it. Renumbering from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
2026-09-16 Turn the display 180 degrees
    Mounted in the car, the USB socket ends up on the wrong side to reach. Turning
    the panel puts it on the good side.
    One constant does it. LovyanGFX adds the panel's offset_rotation into the
    rotation it converts raw touch coordinates with, so the touch panel turns with
    the image and needs no correction of its own - which is the part to confirm on
    the car, since a touch transform left behind would still register presses,
    only mirrored.
    [board_config.hpp]
2026-09-16 Say on the console whether the service access point is up, and why not
    An access point that never appears looks exactly like a firmware that
    does not have the feature, and there was no way to tell the two apart
    from the car. Five conditions can hold the radio down - the setting, the
    engine running, the settle delay, the voltage floor, and the idle
    timeout latch - and stop() only printed when it took down an access
    point that had already come up, which is the one case that was never the
    problem.
    ServiceAp now keeps a current reason the way EmuLog keeps a failure, and
    announce() prints it. Press any key at the console and the dashboard
    says where the radio stands, including how many seconds o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
    [app_controller.cpp]
2026-09-16 Show the access point and its key on the DIAG page
    Having to look up the WPA2 key in a header file is the wrong answer to a
    question asked while standing beside the car with a laptop. The network
    name and the key now sit on the DIAG page, under the peaks, and are
    shown whether or not the radio is up - they are read before joining, not
    after.
    The name turns green and gains a client count once a laptop has actually
    joined, which is the difference between "the radio is up" and "I am on
    it", and the only part of this the status bar's WIFI marker could not
    already tell you.
    The address lost the argument for the third row: the column ends at
    y=266 and the last peak sits at 204, which is a headin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
    [app_controller.cpp]
2026-09-16 Stop the settings page fighting the person using it
    Two faults, one on each side of the link.
    The panel never repainted. applySettings() pushed the new limits into
    the alarm engine and the new brightness into the backlight, but the
    SETUP page's own rows are painted from the settings only when its
    buttons are pressed - so a value changed from the service page left the
    panel showing the old number until the category was switched.
    SetupScreen::refresh() repaints them in place, never rebuilding, because
    this can be reached from inside a button's own callback.
    The web form rebuilt itself after every edit. That threw away the focus,
    jumped the scroll back to the top and replaced the field under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
2026-09-16 Stop the page relying on a method Edge Legacy does not have
    Reported as a blank page on the tuning laptop's Edge, working in IE but
    ugly. Both symptoms are the same page failing in two different places.
    The script called forEach on NodeLists, which is not a method Edge
    Legacy or IE has. The first of the six calls is in the tab wiring at the
    top of the script, and loadStatus() and loadLogs() are at the bottom, so
    the throw meant no data was ever fetched and the page rendered as an
    empty shell. They are plain loops now. The script was otherwise already
    ES5 - no arrow functions, no template literals, no let or const - so
    this was the only thing standing in the way.
    IE is a separate matter and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
2026-09-19 Stop the service page refusing every write in a parked car
    Deleting a log said "the dashboard refused the request". Changing an
    alarm limit, and enabling or disabling an alarm, failed the same way.
    All of them are the 409 from writable(), which asked
    snapshot().rpm >= kEngineRunningRpm
    with no regard for whether the ECU was still talking. Killing the
    ignition cuts the ECU's power mid-frame, so the last frame it ever sent
    stays in the snapshot - often several hundred rpm, sometimes idle
    speed - and the field reads "running" for as long as the dashboard
    stays powered. The engine-off summary was fixed for exactly this on
    2026-09-08 and says so in a comment; writable() was written afterwar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
    [engine_data.hpp]
2026-09-19 File logs by day, and name the bundle for when it was fetched
    The engine stopping rotates the file, so a tuning day is a dozen logs
    and a season is several hundred, all in the card's root and all named
    alike. Both the card and the page became hard to work with long before
    anything technical broke.
    Each day gets a folder now - /20260919/1732_04.emulog - created on the
    first file of the day. Nothing in the .emulog format sees the
    difference; the date has always lived in the name and nowhere else.
    Files already in the root are left exactly where they are. They still
    list, download and delete, under a heading of their own. Moving them
    would mean the dashboard rearranging a card on its own init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
    [emu_log.cpp]
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
